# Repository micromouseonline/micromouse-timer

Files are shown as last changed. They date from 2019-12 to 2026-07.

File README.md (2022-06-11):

# micromouse-timer
Hardware and software for a micromouse classic contest timing system

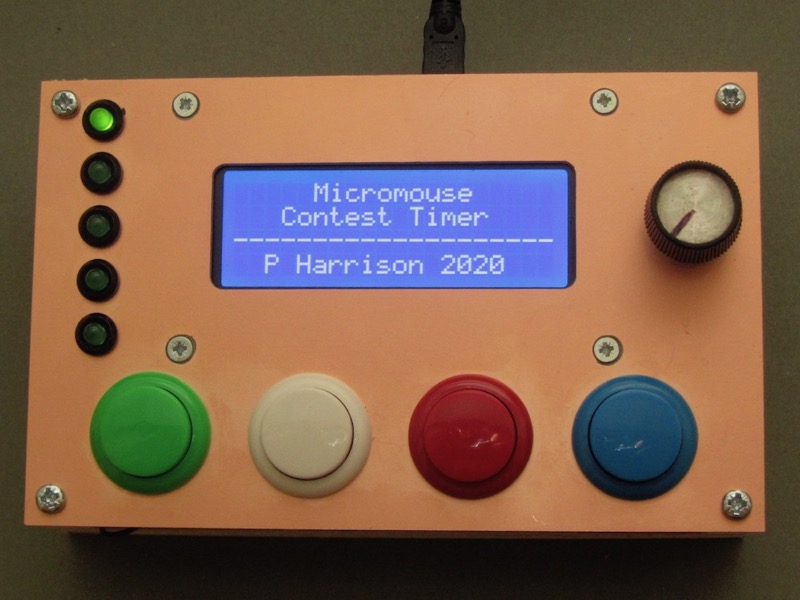
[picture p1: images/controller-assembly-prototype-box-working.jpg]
First prototype


## Design goals
Many micromouse timing systems rely on devices placed in the posts to create a break-beam arrangement. An emitter in one post produces an optical signal that is detected by a matched receiver in the other post. Commercial break-beam devices are available from companies like Omron but they are very expensive, Simpler arrangements an be made with just an LED and phototransistor. For the most reliable operation, the measuring setup really needs to control both the emitter and detector synchronously so that it can detect the breaking of the beam under a wide range of ambient lighting conditions.

This need to connect one controller to both posts makes it necesary to get access to the posts from under the maze. Not only will that require the maze to be raised off the floor by some amount, it makes it very difficult to move the gates after the maze has been set up. Ideally, any timing system should not need any physical connections between components in the maze.

The APEC maze uses a gate sensor system that can be placed anywhere and only needs to be present on one side of the opening. It manages this by using a reflective sensor that measures the distance to the far post. These sensors are similar to those used in the popular Sharp distance sensors by they are have a much faster response time. The Sharp sensors canot be polled every milisecond to get high resolution timing. Unfortunately, making the reflective sensors is quite complicated and requires a certain amount of signal processing circuitry. It is not something that is terribly easy to reproduce.

When making a timing gate sensor, consideration must be given to the robots in the maze. They typically generate very high intensity pulses of IR or visible red light from multiple emitters at 1000Hz or more. Not only should the timing system be unaffected by these pulses, it should also not interfere with the robot's ablity to make measurements. Thus, the robot must not cause timing errors and the timing syste must not make the robots crash.

Finally, there is the issue of ambient lighting levels. These are variable from venue to venue and may vary greatly even during a contest. A venue with natural light may have direct sunlight into the room and, clearly, that light will move around during the day. Other sources of interfering ambient light might include camera lights and camera flashguns. theese too should not interfere with the operation of the timing system.

With so many constraints, it would be natural to seek ever more sophisticated solutions to overcome them.

After several experiments with 'clever' designs, this project tries to make everything as simple as possible.

## Components
There are four components for this timing system
1. gate emitters  - these are just blue LEDs connected to a single Lithium cell with a single current limit resistor. They operate continuously for up to 36 hours between charges.
2. gate receivers - these have a phototransistor with a single load resistor connected to an analogue input channel on an Arduino. The Arduino is also connected to a small 433MHz radio module so that it can send detected changes to a timing controller. Again, a single Lithium cell provides power for at least 20 hours operation.
3. gate controller - the controller is connected directly to the timing management computer with a USB-serial link. It also has a radio receiver so that it can obtain event information from the gate receivers. Each gate receiver sends encoded packets to identify the event and the gate ID. The controller performs the actual timing function and all the data can be stored on an SD card for independent operation or to provide a backup. Power can come from the host USB connection, batteries or a separate power supply. Optionally, a Bluetooth conenction could be made to the host. Sinca all the communication with the gates is wireless, the controller can be placed several metres away from the maze and there are no trailing wires to the maze.
4. timing manager - the software running on the host computer that accepts timing information from the controller, presents it on the display screens and maintains the contest results.

## Gate Operation
Each gate has an emitter and a receiver.

### Emitters
The emitter generates a continuous beam of illumination using blue light. Green light would be a good alternative. While apparently very bright to the human eye, typical micromouse sensor will be relatively insensitive to these wavelengths and, in any case, will perceive the illumnation as part of the background and so it should be compensated for. Blue LEDs have quite high forward voltages of around 2.8 to 3.0 Volts but can still be run from a single Lithium cells with a small series current limiting resistor. Using a resistor value of 39 Ohms with the chosen device limits the maximum current to around 27mA with a fully charged battery at 4.2Volts. As the battery discharges to a nominal 3.7 Volts, the current decreases to about 15mA.

The battery is a Nokia BL-4S with a nominal capacity of 860 mAhr. Once turned on, there should be sufficient capacity for at least 36 hours operation.

A TP4056-based battery charge and protect circuit prevents over discharge of the battery and allows for easy re-charging from a 5V source such as a cell-phone charger of portable power bank.

The emmitter assembly is entirely contained within a typical plastic classic wall. Light shines through a hole in the end of the wall and a corresponding hole is a post. Where the gate must be perpendicular to the wall, a special post is used that contains an embedded reflector at 45 degrees. The reflecto involves a failry large aamount of light loss but is still sufficent for the task. Straight-through emitters might benefit from lower intensity and this could be provided with an additional switch to change the current limit resistor.

### Detectors
The detector circuit is minimal. It consistes of a TEPT5600 visible light phototransistor with a 2200Ohm load resistor on the emitter. The transistor emitter is connected directly to an analogue channel on an arduino mini-pro. The load resistor is selected to give a reading of between 20 and 60 counts when illuminated only by the LED in the timing gate in its normal operating configuration. This is quite a low sensitivity but it ensures that operation will be relatively unaffected even by quite bright ambient illumination right up to the point of saturation of the phototransistor

Attached to a software serial TX pin on the Arduino is a self-contained radio transeiver used only in its transmit mode. the radio is powered down until the gate is interrupted. When messages are to be sent, the radio is powered up, placed in transmit mode and the message is transmitted several times to ensure reliable communication. Aferards, the radio is powered down again to reduce current consumption and prevent interference.

All the radios in the system operate on the same frequency but there should be no natural circumstance where more than one transmits at a time. Thus, the controller needs only one radio and can distinguish the message source from its content.

Like the emitter, the circuitry all fits inside a typical classic maze wall and runs from a BL-4S battery using the same type of TP4056 charge/protect module. In normal operation, the Arduino draws only 12mA and the brief periods of transmission double that for a second or two. Continuous operation should be possible for at least 50 hours with a fully charged BL-4S battery.

### Controller
At the heart of the timing operation is the controller. An Arduino is connected to another LINX radio module which is running continuously in receive mode. It listens for packets from the gate detectors and runs a state machine that looks after all the timing functions related to the current contest.

While intended primarily for micromouse, the same controller could be used for drag race, line follower and time trial contests. Some additional care would be needed to distinguish the transmissions from gates in other contests. The controller passes timing and event notfications to the host computer running event management software using a USB-serial bridge. The same connection can provide power.

So that the controller can be used stand-alone and/or act as a backup to automatic timing, it also has an LCD display and a number of manual buttons that set the state of the system and provide manual gate inputs if needed.

Internally, an SD card records all the incoming and outgoing messages so that they can be retreived for later analysis and toserve as an auxiliary store in case of an error or failure in the management software. Files are time stamped using a data from a battery-backed real time clock module. Note that the RTC battery is not rechargeable and annual maintenance should be carried out to replace the battery and ensure thatthe time and date are correct.

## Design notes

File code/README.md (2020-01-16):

# Micromouse Timer Code

Each folder is a PlatformIO project under Visual Studio Code. The projects should also build under the Arduin IDE if you open the appropriate ___.ino file.

For the operation of the timer hardware, there are just two projects. The gate-detector runs the hardware inside each gate. All the gates run the same code. The gate-controller is the master control box that receives messages from the gates and actually does the timing.

The controller can be run stand-alone. Separate software would be needed for recording the times on a host computer and for the generation of a contest display.

Other projects here are used to test the various parts of the hardware.

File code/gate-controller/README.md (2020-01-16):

# Timing gate Controller

All of the actual timing decisions are made by the gate controller. This device is an Arduino nano with a number of attached peripheral devices incuding a radio receiver that listens for event essages from the individual gates. The controller can be configured for a number of different rule sets and contest types. For the 'standard' micromouse event, the controller keeps track of total maze time, current run time and best run time for that entry. There is no information stored in the controller about which mouse is running.

## Front Panel

On the front panel are a 20x4 LCD character display and an encoder/switch for altering the current mode and operating any other UI on the controller. Four buttons allow the controller to be operated manually if the gates are not functioning or not present. As well as a power indicator, four LEDs indicate the current state of the controller and the events driving it.

## Connectivity

Although it can operate in a completely stand-alone mode, the controller would normally be connected to a host computer that will keep a record of the run times and look after any dislay devices for the conestants and spectators. Communication with the host is performed over a serial link (at 57600 baud) using the Arduino's built-in serial bridge. This has two side-effects. One is that the device can be programmed over the same link, the other is that connecting the cable will reset the controller. Since this connection is also how it gets its power, that is not a great problem.

Optionally, the internal BlueTooth transeiver can be used for serial communications if a plain USB power supply is used. The communications speed is still 57600 baud and the two serial connections share the same USART of the Arduino.

## Storage

Also present are a micro SD card reader/writer and a Real Time CLock. The SD card interface makes it possible for al messages and times to be saved to a suitable SD Card for subsequent analysis and reporting or in case the host connection fails or is not present. With the time data from the RTC, files and events can be properly time stamped. Note that the RTC is battery backed but does not incorporate a charger. The battery life of the clock is given as 1 year. Without the battery, all times will be relative to the last application of pwer to the device.

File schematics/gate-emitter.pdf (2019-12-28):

28/12/2019 09:20 /Users/peterharrison/OneDrive/Documents/eagle/projects/Timing-Gate/gate-emitter.sch (Sheet: 1/1)

BATTERY-CHARGER-LI-PROT

3.3V

GND

OVLGB0C6B9 | OVLGB0C6B9
GND | GND
39R | 39R | B+B-

IN+

IN-

OUT+ OUT- | +

+
ID

ID

D1 | D2
R1 | R2

## Sheet:

A

B

C

D

1 | 2 | 3 | 4 | 5 | 6

A

B

C

D

1 | 2 | 3 | 4 | 5 | 6

## gate-emitter

28/12/2019 09:19
1/1
USB | NOKIA BL-4S

The start gate uses two sensors. one across the posts and one about 2/3 of the way back into the cell. Goal gates use only one sensor placed across the posts. The post sensor is D1/R1

If the other sensor is not used, omit both R2 and D2

OVLGB0C6B9 is a high intensity, narrow beam blue 5mm LED.

The battery can be any LiPo or LiIon
single cell type that will fit. The Nokia BL-4S has a capacity of 860mA

and is a perfect size to fit inside a classic wall. Circut power consumption is a few tens of mA

at idle.

Battery management is provided by an ebay module holding a TP4056 charger along with a discharge protection circuit. Micromouse Timer Gate Emitter

# (c) 2019 Peter Harrison https://github.com/micromouseonline/micromouse-timer

S1 is a small slide switch sized to fit inside the wall. surfacemount types are suitable here. Use anything

that will fit.

Peter Harrison

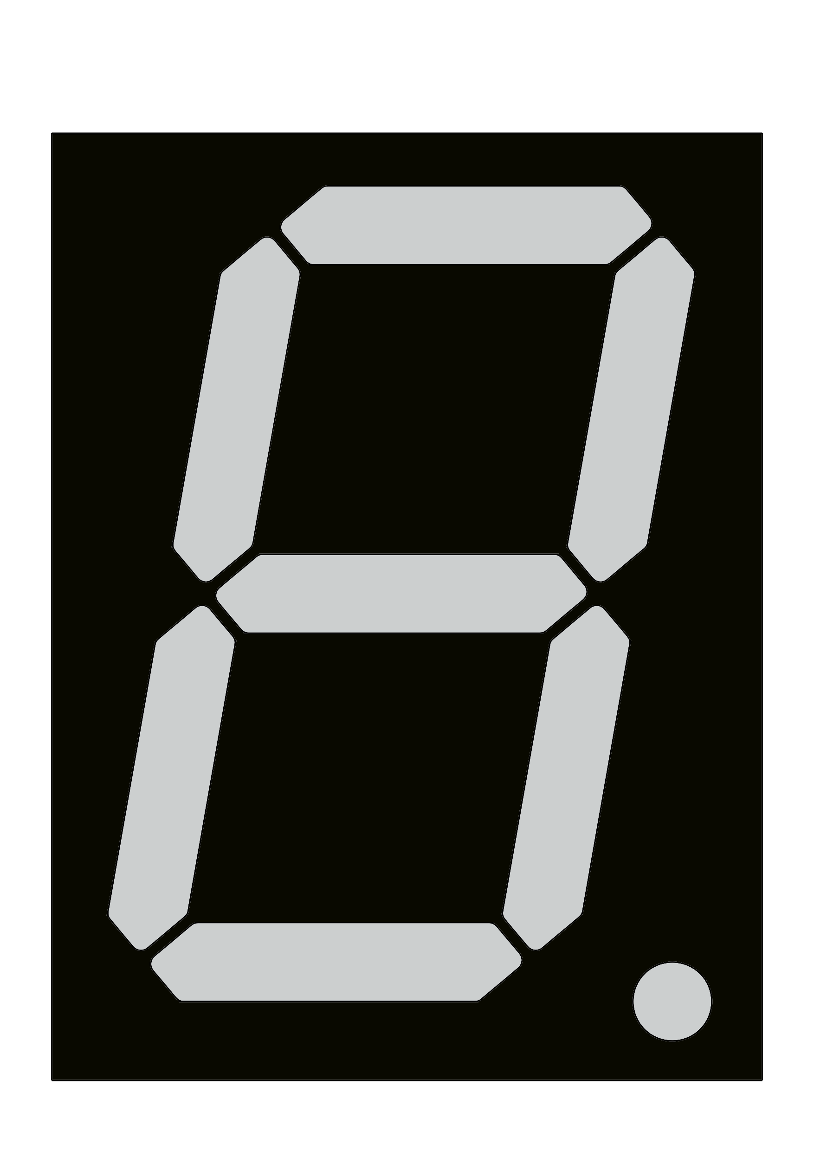
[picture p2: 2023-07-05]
hardware/seven-segment-display/single-digit-mask.png

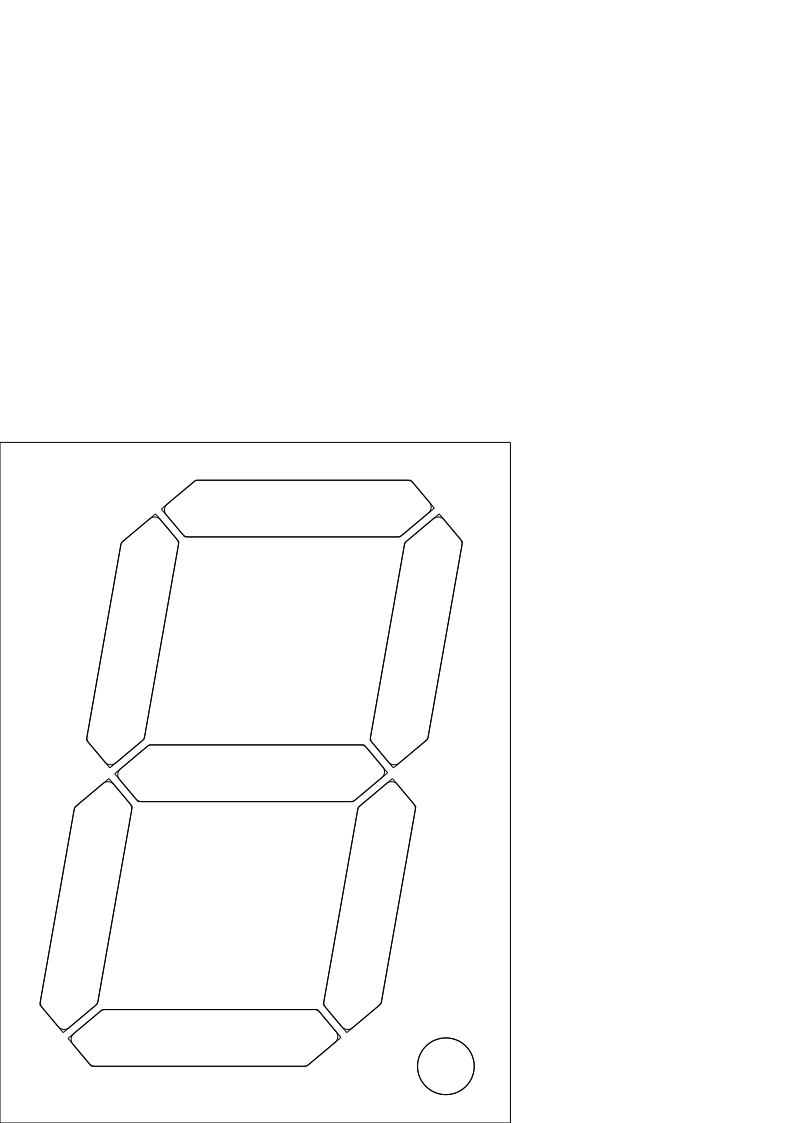
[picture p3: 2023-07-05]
hardware/seven-segment-display/single-digit.png

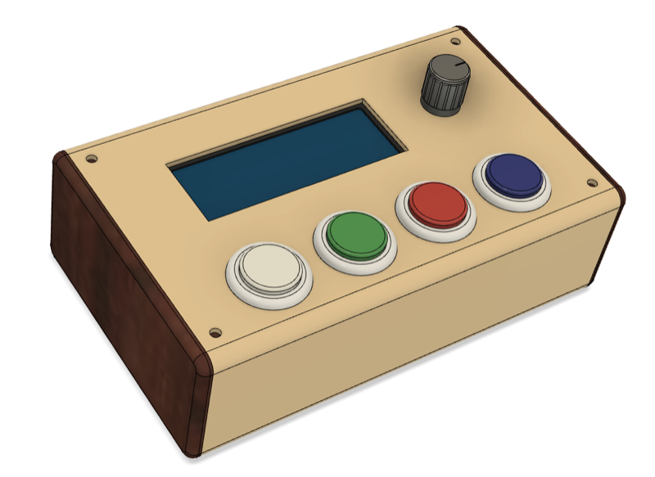
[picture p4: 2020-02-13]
images/controller-render-V2a.png

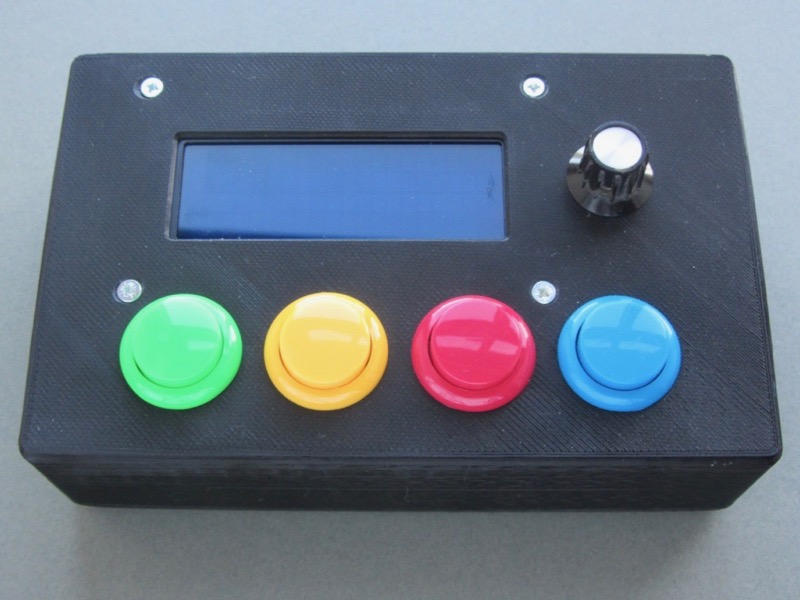
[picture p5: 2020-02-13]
images/controller-boxed.jpg

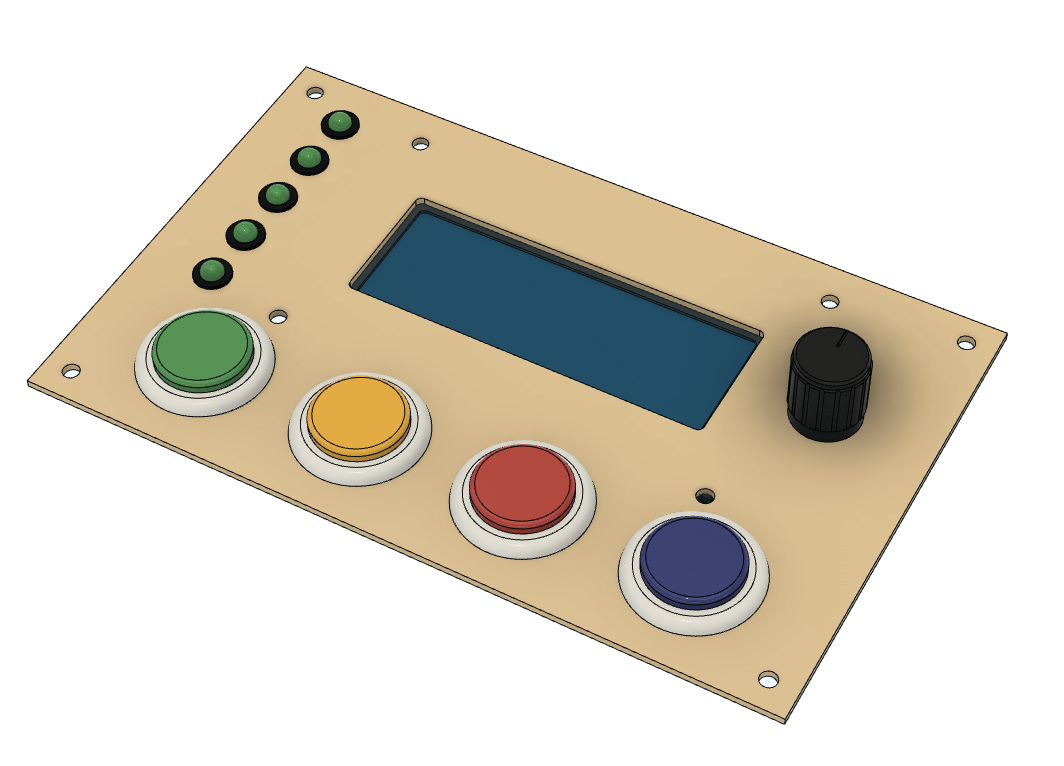
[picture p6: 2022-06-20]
images/front-panel.png

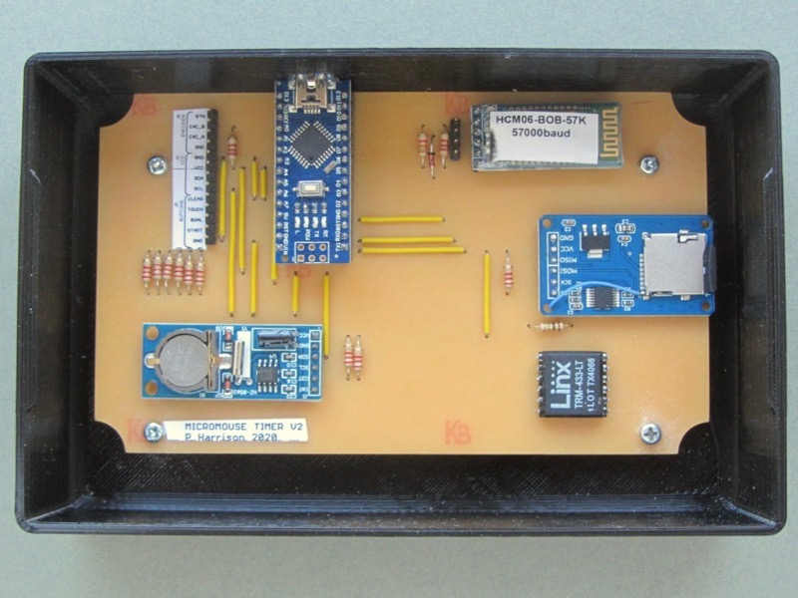
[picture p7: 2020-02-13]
images/controller-circuit-board.jpg

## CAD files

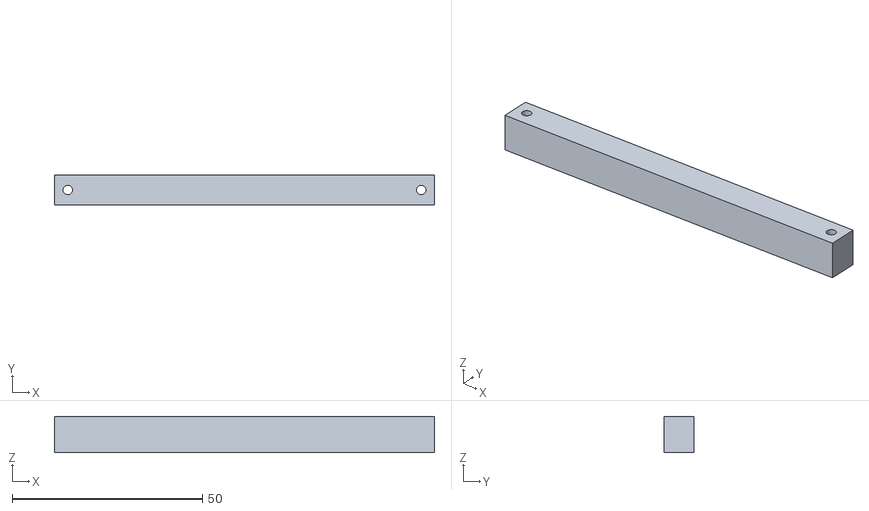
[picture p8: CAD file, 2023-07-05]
hardware/controller-enclosure/LCD-spacer.stl
100.0 x 8.00 x 9.60

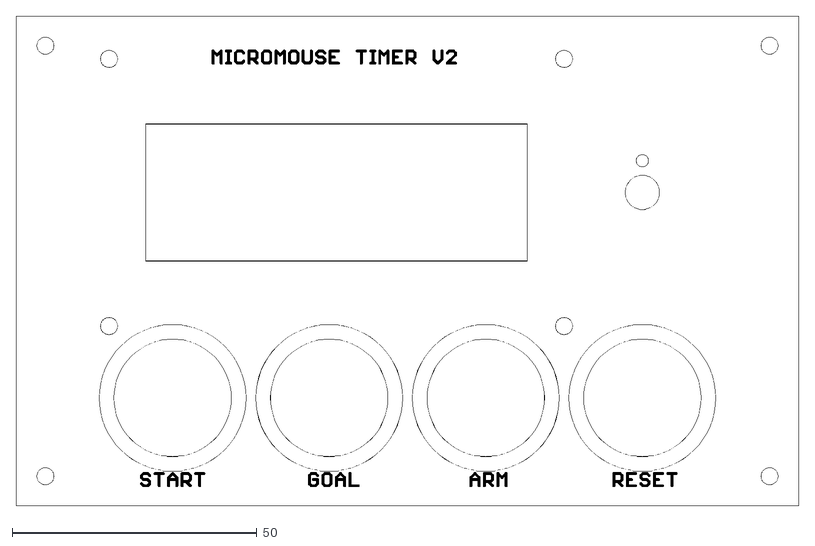
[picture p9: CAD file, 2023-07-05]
hardware/controller-pcb/gate-controller-top-pane-plywoodl.dxf
160.0 x 100.0

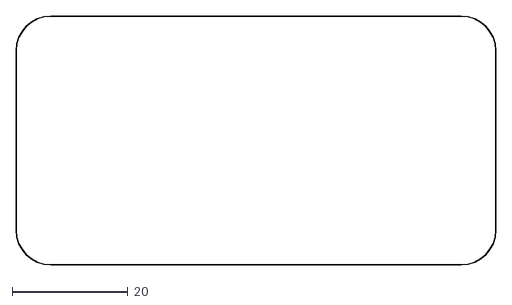
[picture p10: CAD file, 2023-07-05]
hardware/gate-charger/4-way-charger-outline.dxf
83.0 x 43.0

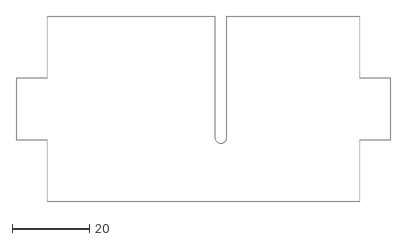
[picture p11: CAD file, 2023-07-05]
hardware/gate-detector/gate-detector.dxf
97.1 x 48.1

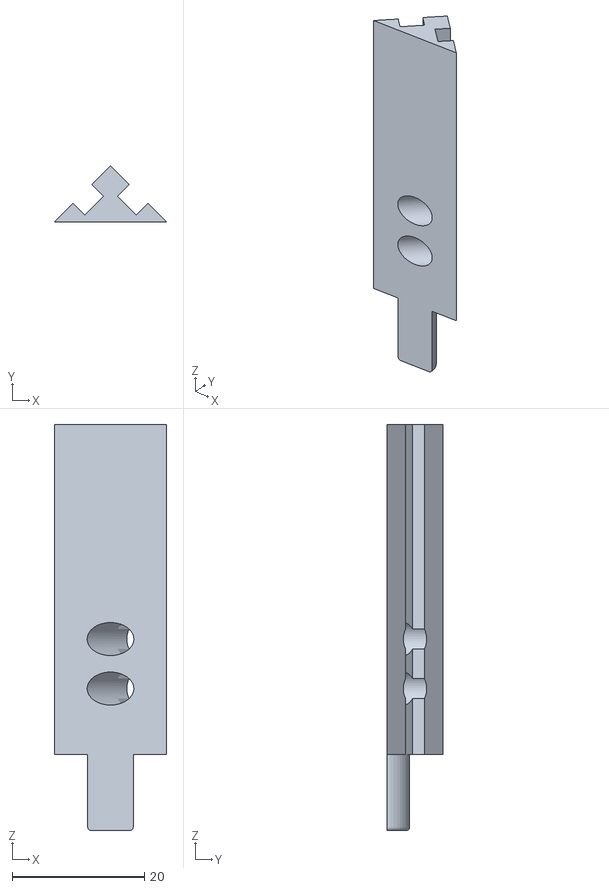
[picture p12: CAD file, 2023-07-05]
hardware/gate-post-and-wall-parts/post-half-double-sensor-one-way.stl
17.0 x 8.49 x 61.5

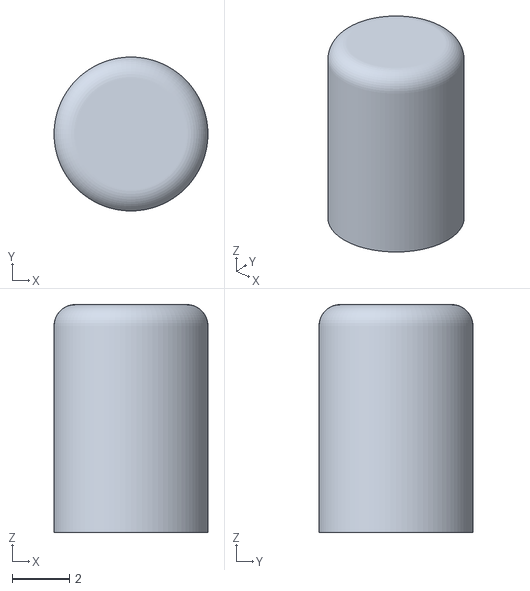
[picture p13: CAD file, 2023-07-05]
hardware/seven-segment-display/dp-small.stl
5.40 x 5.40 x 8.00

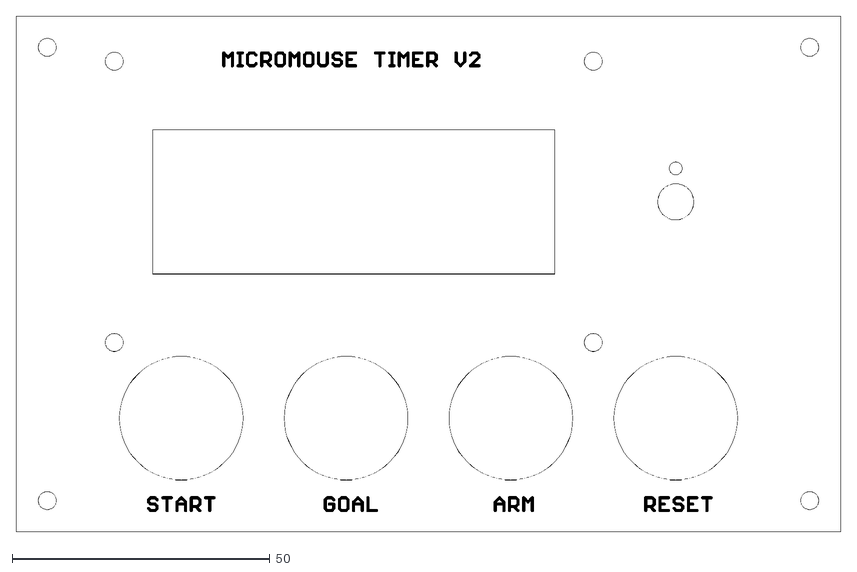
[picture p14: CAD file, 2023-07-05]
hardware/controller-enclosure/gate-controller-top-panel.dxf
160.0 x 100.0

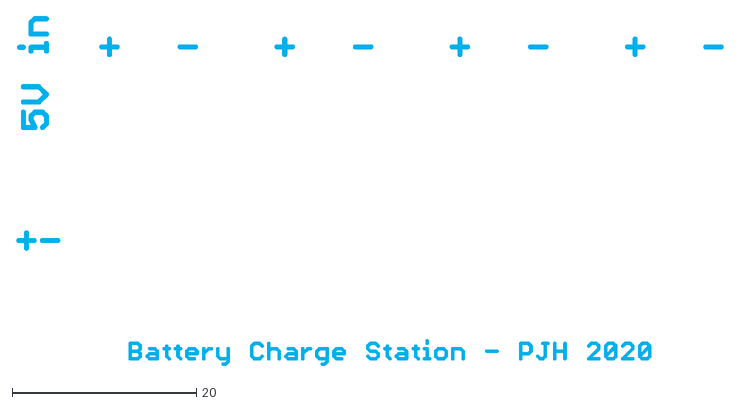
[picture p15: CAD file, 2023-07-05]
hardware/gate-charger/4-way-charger-text.dxf
76.7 x 37.9

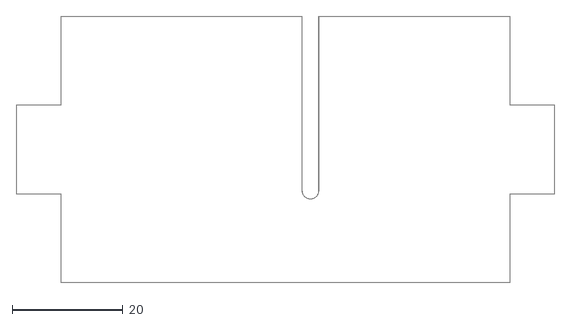
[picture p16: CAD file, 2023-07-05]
hardware/gate-detector/gate-detector-board-outline.dxf
97.1 x 48.1

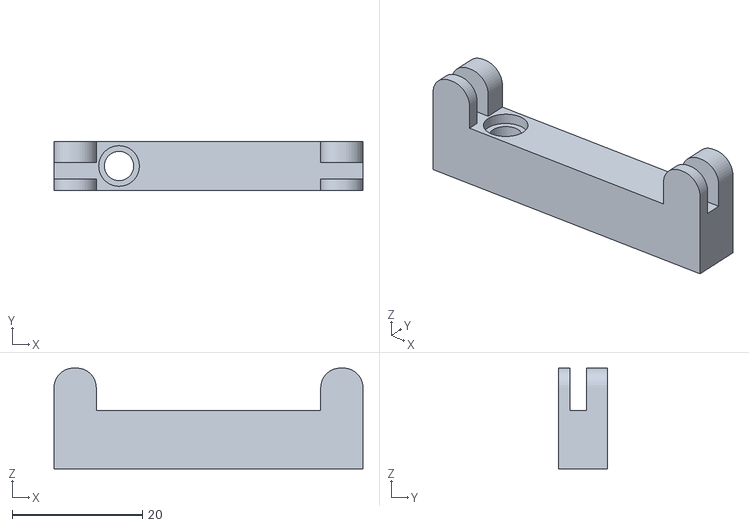
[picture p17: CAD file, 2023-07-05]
hardware/gate-post-and-wall-parts/emitter-holder.stl
47.5 x 7.50 x 15.5

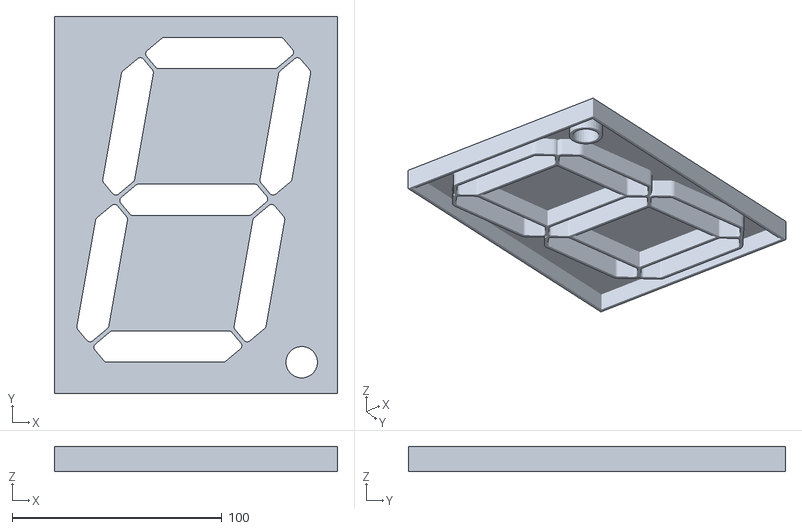
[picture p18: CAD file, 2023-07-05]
hardware/seven-segment-display/seven-sement-shield.stl
135.0 x 180.0 x 12.0

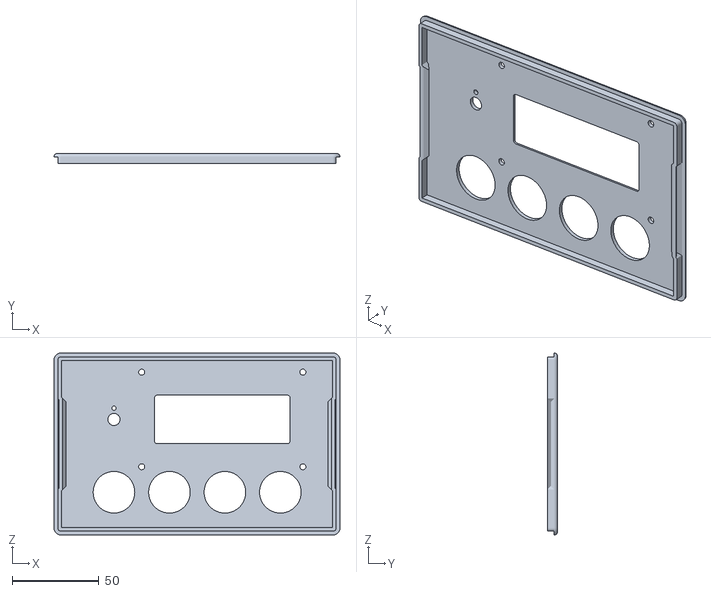
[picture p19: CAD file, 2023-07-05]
hardware/controller-enclosure/gate-controller-case-lid.stl
165.0 x 6.00 x 105.0

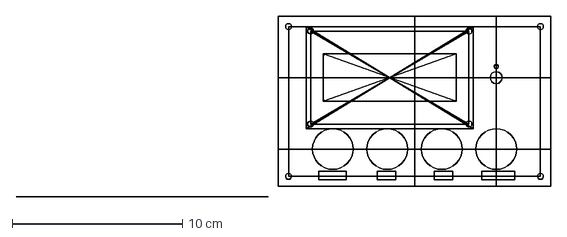
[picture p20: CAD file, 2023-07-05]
hardware/controller-pcb/gate-controller-Front Panel V2 v6.dxf
31.4 x 10.6 cm

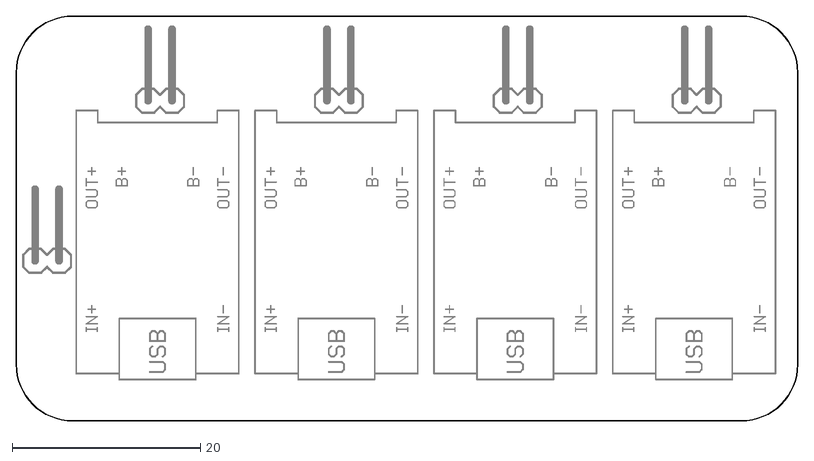
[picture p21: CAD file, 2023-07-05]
hardware/gate-charger/4-way-charger-fill.dxf
83.0 x 43.0

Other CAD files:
hardware/gate-detector/gate-detector-mirrored (copy).dxf
hardware/gate-post-and-wall-parts/classic-post-half-sensor-hole.stl
hardware/seven-segment-display/seven-segment-body-upright-milled.dxf
hardware/controller-enclosure/controller-panel.stl
hardware/controller-enclosure/gate-controller-V2.dxf
hardware/controller-enclosure/gate-controller-case-body.stl
hardware/controller-enclosure/spacer-9.6mm.stl
hardware/controller-pcb/gate-controller-case-body.stl
hardware/controller-pcb/gate-controller-mirrored-V2.dxf
hardware/gate-charger/4-way-charger-brd-nofill.dxf
hardware/gate-detector/gate-detector-mirrored.dxf
hardware/gate-post-and-wall-parts/detector-holder-v2.stl
hardware/gate-post-and-wall-parts/detector-holder.stl
hardware/gate-post-and-wall-parts/emitter-detector-twin-holder.stl
hardware/gate-post-and-wall-parts/maze-gate-emitter-detector-holder-v2.stl
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

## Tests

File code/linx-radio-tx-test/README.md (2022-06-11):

# Linx radio transmission/reception tests

The Linx TRM-433 tranceiver modules are simple On-Off Keying (OOK) devices operating in the 433MHx radio band. The same device is also available in other bands appropriate to their country of use and local radio regulations.

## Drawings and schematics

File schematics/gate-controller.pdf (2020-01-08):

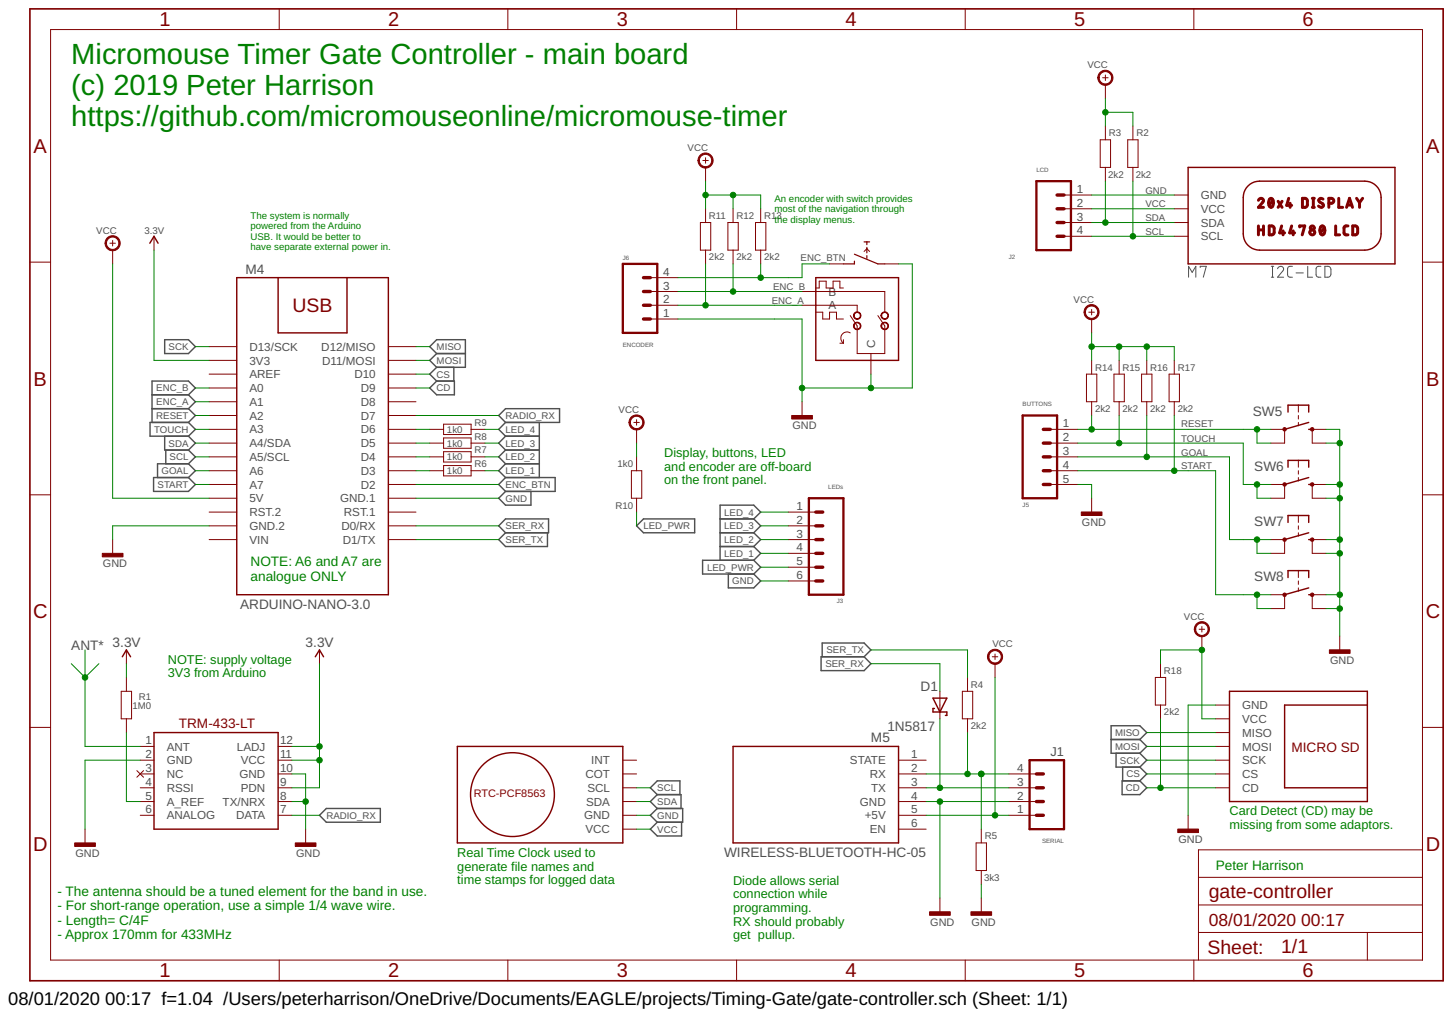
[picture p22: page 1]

Micromouse Timer Gate Controller - main board VCC

(c) 2019 Peter Harrison
https://github.com/micromouseonline/micromouse-timer

3V3 D13/SCK M4
USB
D1/TX D0/RX RST.1 GND.1 D2 D3 D4 D5 D6 D7 D8 D9 D10 D11/MOSI D12/MISO
A3A2A1A0AREF

An encoder with switch provides most of the navigation through
the display menus.

2 | | VCC
3 | | SDA
4 | | SCL

The system is normally powered from the Arduino USB. It would be better to

have separate external power in.

Display, buttons, LED
and encoder are off-board

on the front panel. NOTE: A6 and A7 are
VIN GND.2 RST.2

VCC MISO MOSI SCK CS

INT COT SCL SDA GND

4 +5V | 2
5 EN | 1

Card Detect (CD) may be missing from some adaptors. Diode allows serial connection while

Real Time Clock used to
generate file names and
time stamps for logged data

- The antenna should be a tuned element for the band in use. - For short-range operation, use a simple 1/4 wave wire. - Length= C/4F

programming. RX should probably
get pullup.

08/01/2020 00:17 f=1.04 /Users/peterharrison/OneDrive/Documents/EAGLE/projects/Timing-Gate/gate-controller.sch (Sheet: 1/1)

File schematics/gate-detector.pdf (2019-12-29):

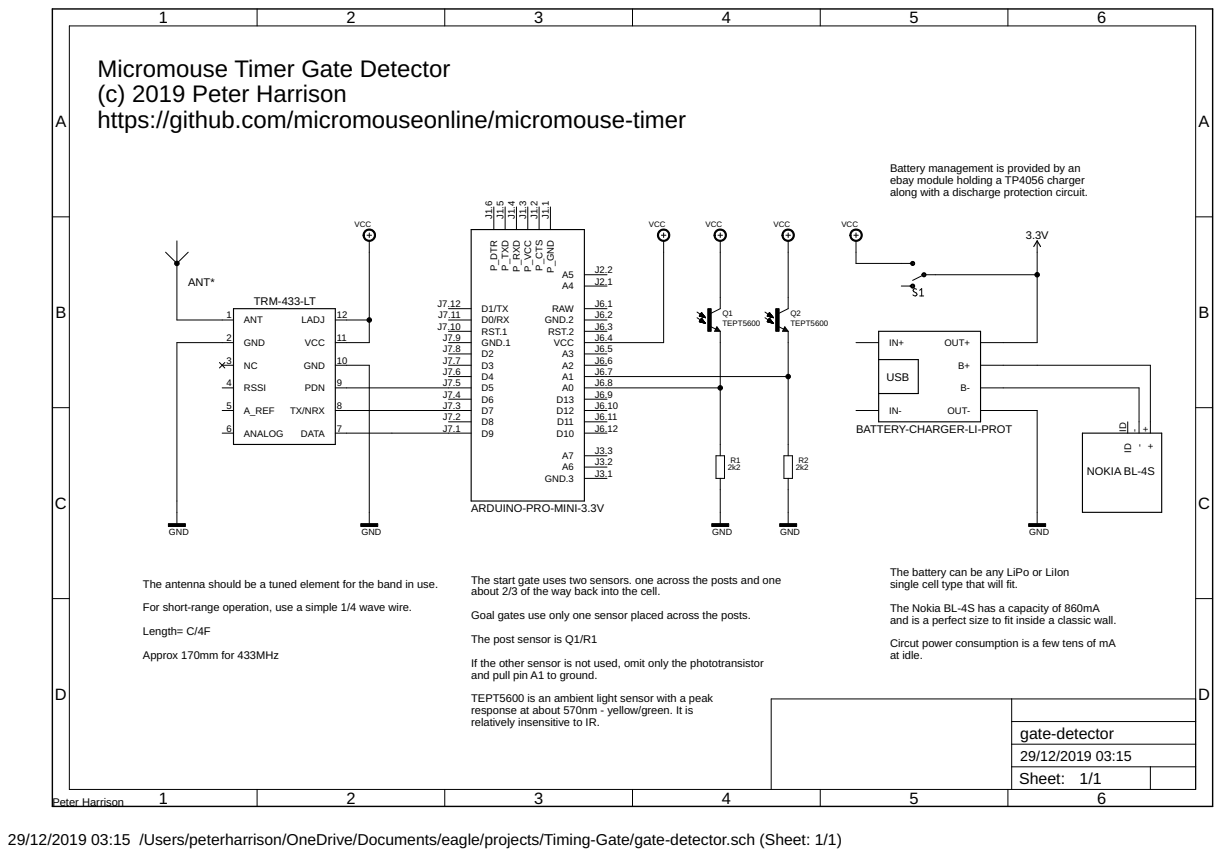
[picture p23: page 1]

ebay module holding a TP4056 charger along with a discharge protection circuit. Micromouse Timer Gate Detector
(c) 2019 Peter Harrison
https://github.com/micromouseonline/micromouse-timer

Battery management is provided by an

BATTERY-CHARGER-LI-PROT
2k2 GND

The start gate uses two sensors. one across the posts and one
about 2/3 of the way back into the cell. Goal gates use only one sensor placed across the posts. The post sensor is Q1/R1

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

If the other sensor is not used, omit only the phototransistor and pull pin A1 to ground. TEPT5600 is an ambient light sensor with a peak

response at about 570nm - yellow/green. It is
relatively insensitive to IR.

29/12/2019 03:15 /Users/peterharrison/OneDrive/Documents/eagle/projects/Timing-Gate/gate-detector.sch (Sheet: 1/1)

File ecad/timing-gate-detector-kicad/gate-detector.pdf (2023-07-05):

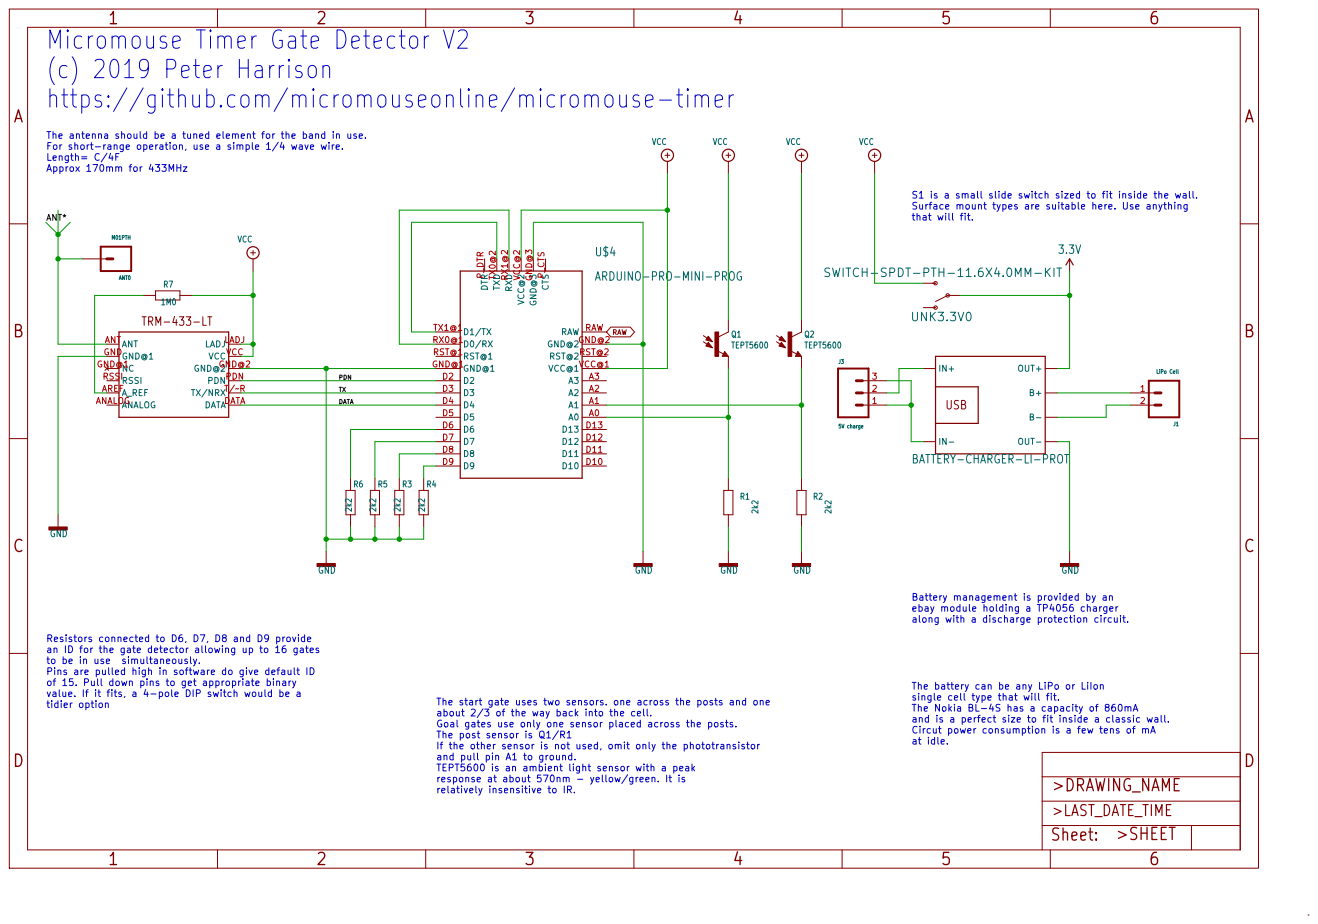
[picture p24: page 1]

at idle. Micromouse Timer Gate Detector V2
(c) 2019 Peter Harrison
https://github.com/micromouseonline/micromouse-timer

that will fit. The antenna should be a tuned element for the band in use. For short-range operation, use a simple 1/4 wave wire.

S1 is a small slide switch sized to fit inside the wall. Surface mount types are suitable here. Use anything

ARDUINO-PRO-MINI-PROG R7

ebay module holding a TP4056 charger
along with a discharge protection circuit.

Resistors connected to D6, D7, D8 and D9 provide
an ID for the gate detector allowing up to 16 gates
to be in use simultaneously.
Pins are pulled high in software do give default ID
of 15. Pull down pins to get appropriate binary
value. If it fits, a 4-pole DIP switch would be a
tidier option

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

The start gate uses two sensors. one across the posts and one
about 2/3 of the way back into the cell.
Goal gates use only one sensor placed across the posts.
The post sensor is Q1/R1
If the other sensor is not used, omit only the phototransistor
and pull pin A1 to ground.
TEPT5600 is an ambient light sensor with a peak
response at about 570nm - yellow/green. It is
relatively insensitive to IR.

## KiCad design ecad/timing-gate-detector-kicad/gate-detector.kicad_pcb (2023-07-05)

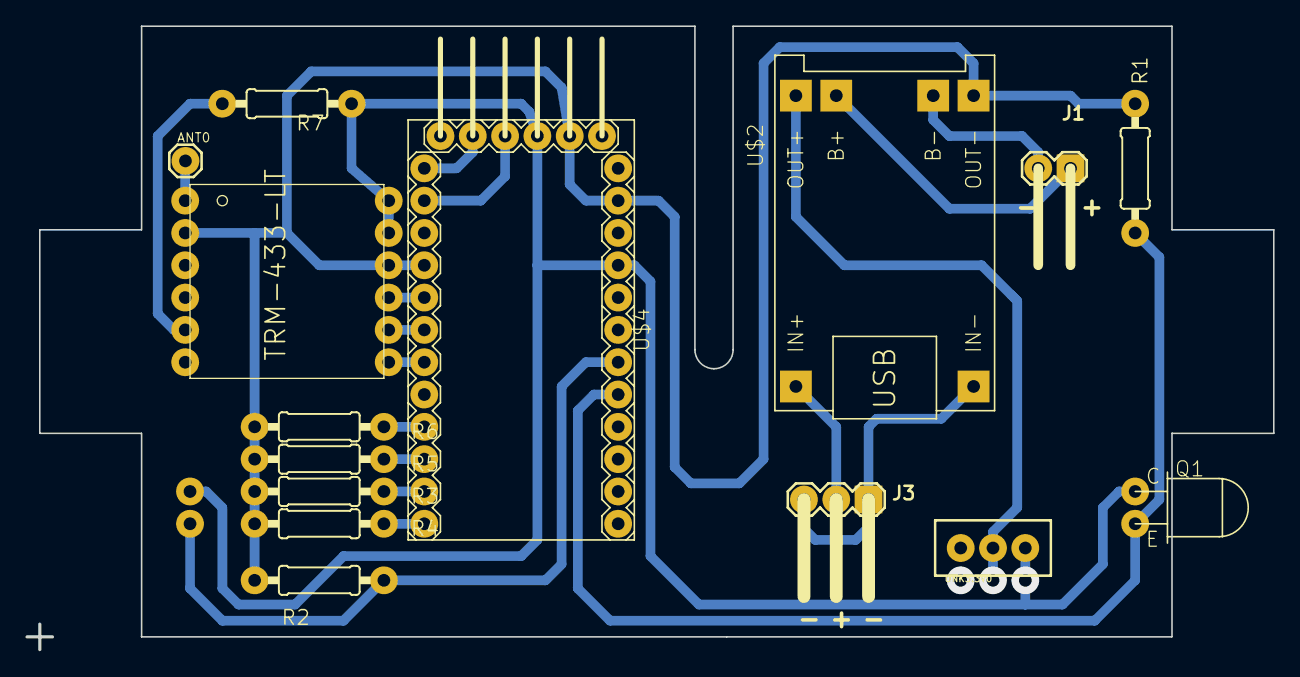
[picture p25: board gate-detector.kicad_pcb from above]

Board: 6 copper layers, 98.0 x 49.0 mm, 16 parts (1 on the bottom side), 20 nets.

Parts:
ANT0: M01PTH; 1X01
J1: LiPo Cell; 1X02_RA_PTH_MALE_MILL
J3: 5V charge; 1X03_RA_PTH_MILL
Q1, Q2: TEPT5600; PHOTOTRANSISTOR-TO5-SIDE
R1, R2, R3, R4, R5, R6: 2k2; AXIAL-0207_0.4
R7: 1M0; AXIAL-0207_0.4
U$1: TRM-433-LT; LINX-TRM-433-LT
U$2: BATTERY-CHARGER-LI-PROT
U$4: ARDUINO-PRO-MINI-PROG
UNK3.3V0: SWITCH_SPDT_PTH_11.6X4.0MM_KIT

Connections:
3.3V: U$2.OUT+, UNK3.3V0.2
ANT*: ANT0.1, U$1.ANT
DATA: U$1.DATA, U$4.D4
GND: R1.1, R2.1, R3.1, R4.1, R5.1, R6.1, U$1.GND, U$1.GND@2, U$2.OUT-, U$4.GND@1, U$4.GND@2, U$4.GND@3
unnamed: Q2.E, R2.2, U$4.A1
unnamed: J1.1, U$2.B+
unnamed: R4.2, U$4.D9
unnamed: R3.2, U$4.D8
unnamed: R5.2, U$4.D7
unnamed: Q1.E, R1.2, U$4.A0
unnamed: J1.2, U$2.B-
unnamed: R6.2, U$4.D6
unnamed: R7.2, U$1.AREF
unnamed: J3.2, U$2.IN+
unnamed: J3.1, J3.3, U$2.IN-
unnamed: U$4.TX0@2, U$4.TX1@1
unnamed: U$4.RX0@1, U$4.RX1@2
PDN: U$1.PDN, U$4.D2
TX: U$1.T/~R, U$4.D3
VCC: Q1.C, Q2.C, R7.1, U$1.LADJ, U$1.VCC, U$4.VCC@1, U$4.VCC@2, UNK3.3V0.3

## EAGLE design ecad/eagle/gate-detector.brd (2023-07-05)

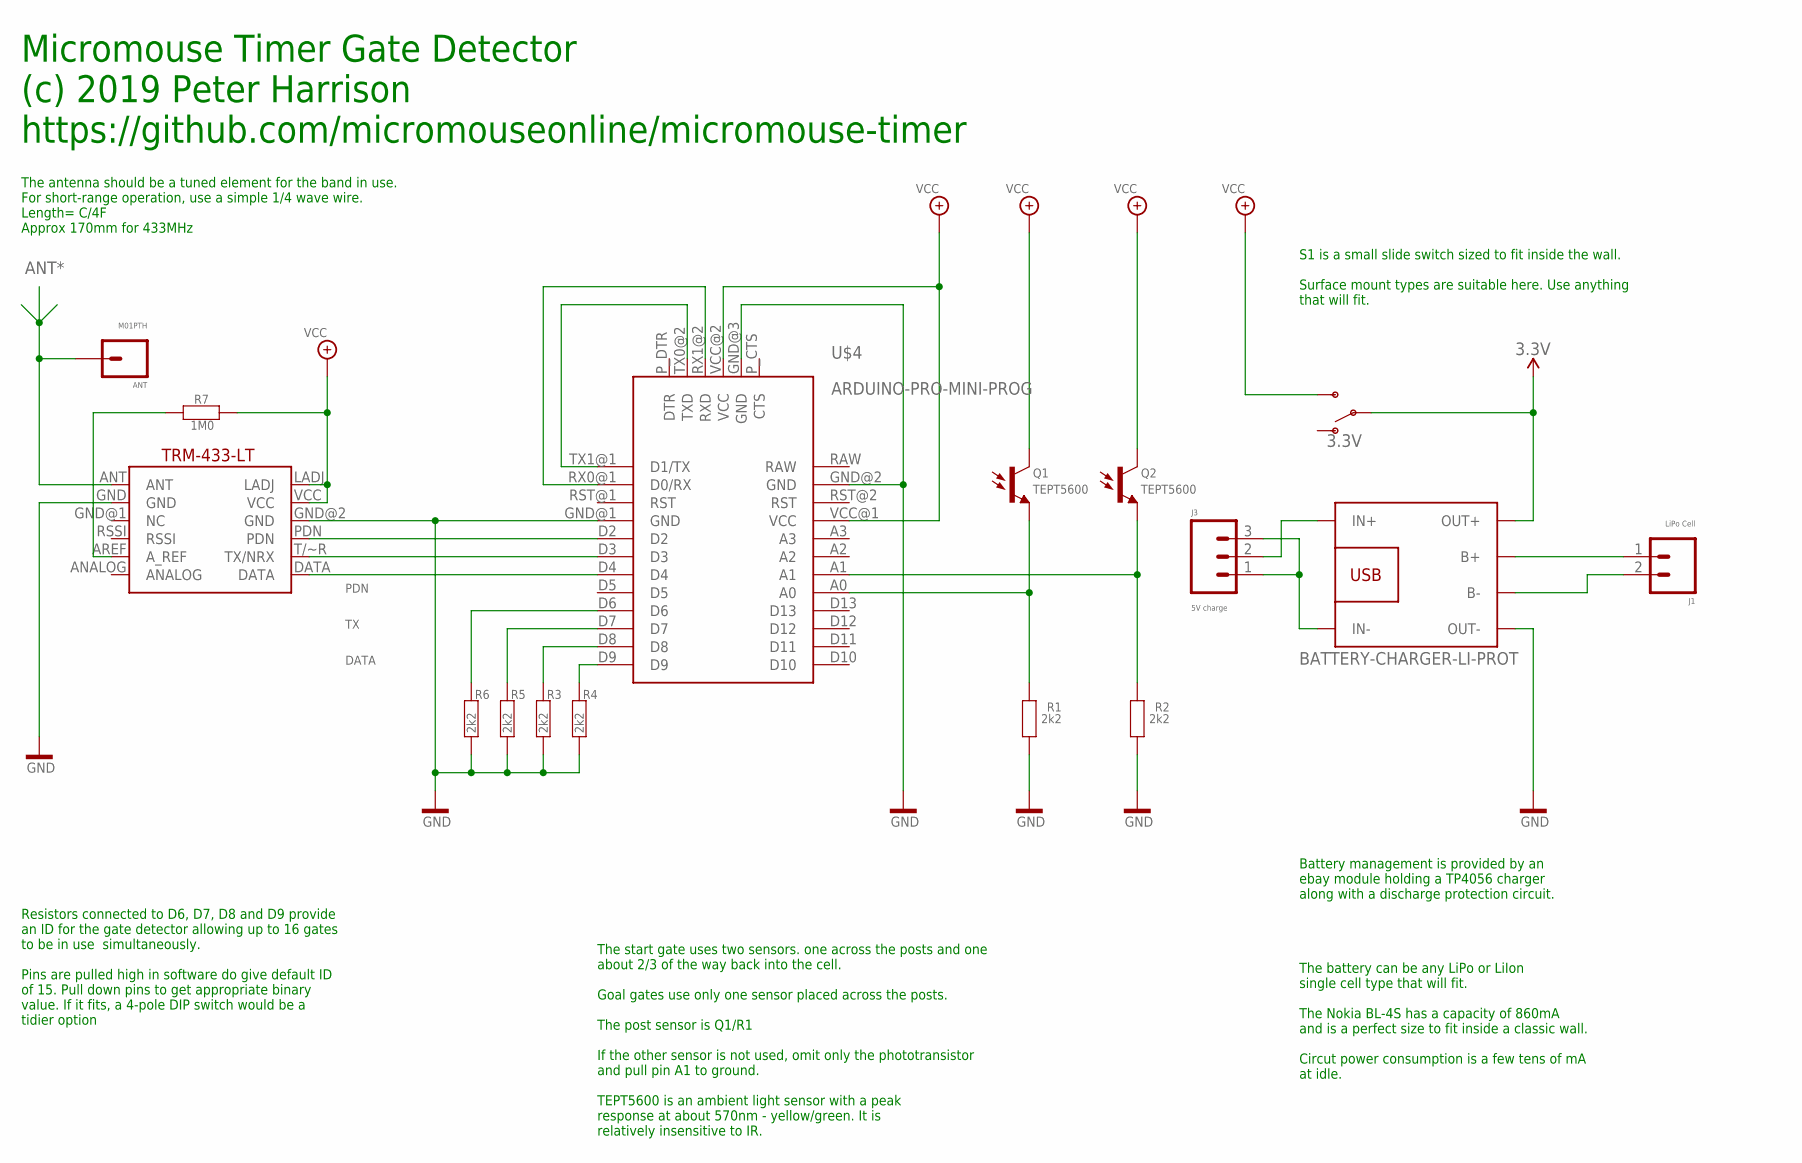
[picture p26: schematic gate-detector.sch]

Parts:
3.3V: SWITCH-SPDT-PTH-11.6X4.0MM-KIT; SWITCH_SPDT_PTH_11.6X4.0MM_KIT
ANT: M01PTH; 1X01
J1: LiPo Cell; 1X02_RA_PTH_MALE_MILL
J3: 5V charge; 1X03_RA_PTH_MILL
Q1, Q2: TEPT5600; PHOTOTRANSISTOR-TO5-SIDE
R1, R2, R3, R4, R5, R6: 2k2; AXIAL-0207_0.4
R7: 1M0; AXIAL-0207_0.4
U$1: TRM-433-LT; LINX-TRM-433-LT
U$2: BATTERY-CHARGER-LI-PROT
U$4: ARDUINO-PRO-MINI-PROG

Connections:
3.3V: 3.3V.2, U$2.OUT+
ANT*: ANT.1, U$1.ANT
DATA: U$1.DATA, U$4.D4
GND: R1.1, R2.1, R3.1, R4.1, R5.1, R6.1, U$1.GND, U$1.GND@2 (GND), U$2.OUT-, U$4.GND@1 (GND), U$4.GND@2 (GND), U$4.GND@3 (GND)
unnamed: Q2.E, R2.2, U$4.A1
unnamed: J1.1, U$2.B+
unnamed: R4.2, U$4.D9
unnamed: R3.2, U$4.D8
unnamed: R5.2, U$4.D7
unnamed: Q1.E, R1.2, U$4.A0
unnamed: J1.2, U$2.B-
unnamed: R6.2, U$4.D6
unnamed: R7.2, U$1.AREF (A_REF)
unnamed: J3.2, U$2.IN+
unnamed: J3.1, J3.3, U$2.IN-
unnamed: U$4.TX0@2 (TXD), U$4.TX1@1 (D1/TX)
unnamed: U$4.RX0@1 (D0/RX), U$4.RX1@2 (RXD)
PDN: U$1.PDN, U$4.D2
RAW: U$4.RAW
TX: U$1.T/~R (TX/NRX), U$4.D3
VCC: 3.3V.3 (S), Q1.C, Q2.C, R7.1, U$1.LADJ, U$1.VCC, U$4.VCC@1 (VCC), U$4.VCC@2 (VCC)

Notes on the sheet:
The antenna should be a tuned element for the band in use. For short-range operation, use a simple 1/4 wave wire. Length= C/4F Approx 170mm for 433MHz
The start gate uses two sensors. one across the posts and one about 2/3 of the way back into the cell. Goal gates use only one sensor placed across the posts. The post sensor is Q1/R1 If the other sensor is not used, omit only the phototransistor and pull pin A1 to ground. TEPT5600 is an ambient li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
The battery can be any LiPo or LiIon single cell type that will fit. The Nokia BL-4S has a capacity of 860mA and is a perfect size to fit inside a classic wall. Circut power consumption is a few tens of mA at idle.
Battery management is provided by an ebay module holding a TP4056 charger along with a discharge protection circuit.
Micromouse Timer Gate Detector (c) 2019 Peter Harrison https://github.com/micromouseonline/micromouse-timer
S1 is a small slide switch sized to fit inside the wall. Surface mount types are suitable here. Use anything that will fit.
Resistors connected to D6, D7, D8 and D9 provide an ID for the gate detector allowing up to 16 gates to be in use simultaneously. Pins are pulled high in software do give default ID of 15. Pull down pins to get appropriate binary value. If it fits, a 4-pole DIP switch would be a tidier option

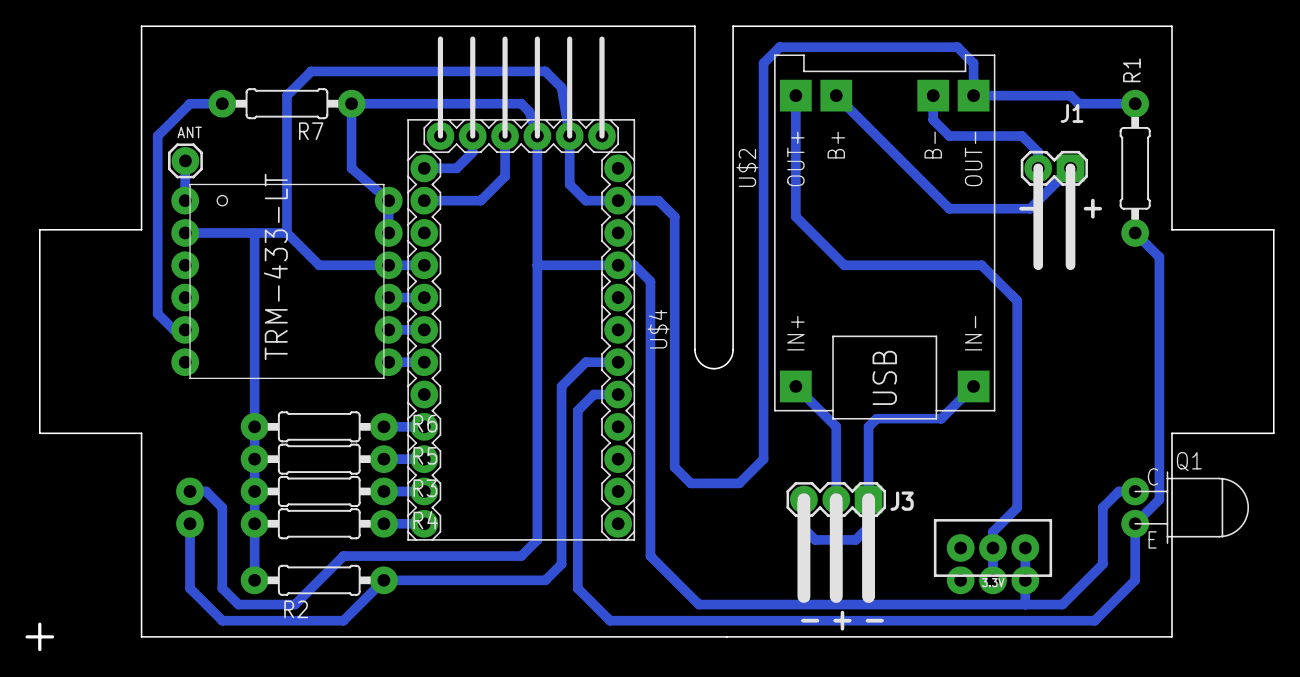
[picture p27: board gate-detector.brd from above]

Board: 2 copper layers, 98.0 x 49.0 mm, 16 parts (1 on the bottom side), 20 nets.

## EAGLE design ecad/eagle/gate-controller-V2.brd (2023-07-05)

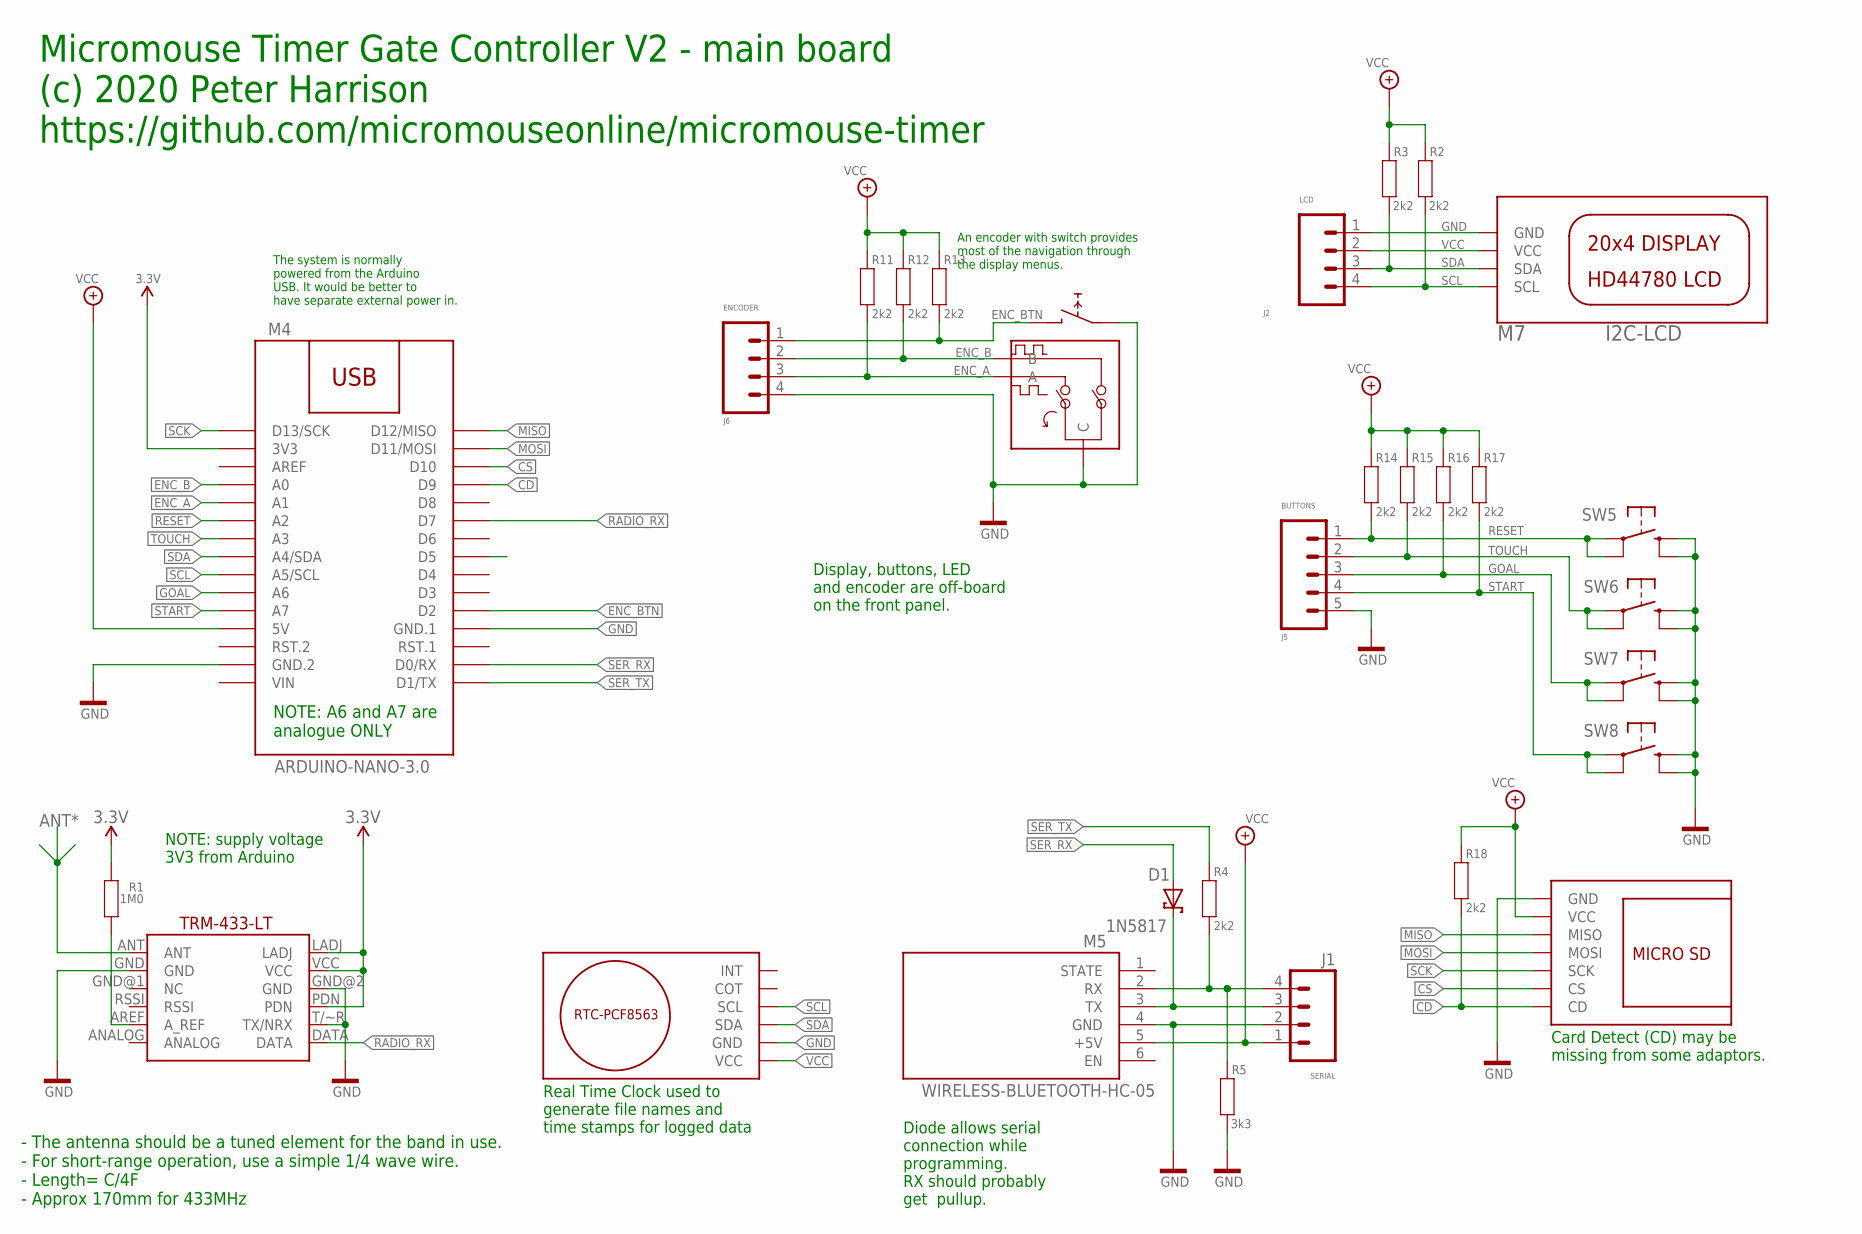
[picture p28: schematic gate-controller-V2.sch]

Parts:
D1: 1N5817; DO35-7
J1: SERIAL; 1X04
J2: LCD; 1X04
J5: BUTTONS; 1X05
J6: ENCODER; 1X04
M2: RTC-PCF8563
M3: TRM-433-LT; LINX-TRM-433-LT
M4: ARDUINO-NANO-3.0
M5: WIRELESS-BLUETOOTH-HC-05
M6: MICRO-SD-ADAPTOR
R1: 1M0; AXIAL-0207_0.4
R2, R3, R4, R11, R12, R13, R14, R15, R16, R17, R18: 2k2; AXIAL-0207_0.4
R5: 3k3; AXIAL-0207_0.4

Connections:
3V3: M3.LADJ, M3.PDN, M3.VCC, M4.3V3, R1.2
ANT*: M3.ANT
CD: M4.D9, M6.CD, R18.1
CS: M4.D10, M6.CS
D5: M4.D5
ENC_A: J6.3, M4.A1, R11.1
ENC_B: J6.2, M4.A0, R12.1
ENC_BTN: J6.1, M4.D2, R13.1
GND: J1.2, J2.1, J5.5, J6.4, M2.GND, M3.GND, M3.GND@2 (GND), M3.T/~R (TX/NRX), M4.GND@1 (GND.2), M4.GND@2 (GND.1), M5.4 (GND), M6.GND, R5.1
GOAL: J5.3, M4.A6, R16.1
MISO: M4.D12 (D12/MISO), M6.MISO
MOSI: M4.D11 (D11/MOSI), M6.MOSI
unnamed: M3.AREF (A_REF), R1.1
unnamed: J1.4, M5.2 (RX), R4.1, R5.2
unnamed: D1.C, J1.3, M5.3 (TX)
RADIO_RX: M3.DATA, M4.D7
RESET: J5.1, M4.A2, R14.1
SCK: M4.D13 (D13/SCK), M6.SCK
SCL: J2.4, M2.SCL, M4.A5 (A5/SCL), R2.1
SDA: J2.3, M2.SDA, M4.A4 (A4/SDA), R3.1
SER_RX: D1.A, M4.RX0 (D0/RX)
SER_TX: M4.TX1 (D1/TX), R4.2
START: J5.4, M4.A7, R17.1
TOUCH: J5.2, M4.A3, R15.1
VCC: J1.1, J2.2, M2.VCC, M4.5V, M5.5 (+5V), M6.VCC, R2.2, R3.2, R11.2, R12.2, R13.2, R14.2, R15.2, R16.2, R17.2, R18.2
VIN: M4.VIN

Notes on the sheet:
- The antenna should be a tuned element for the band in use. - For short-range operation, use a simple 1/4 wave wire. - Length= C/4F - Approx 170mm for 433MHz
Micromouse Timer Gate Controller V2 - main board (c) 2020 Peter Harrison https://github.com/micromouseonline/micromouse-timer
Card Detect (CD) may be missing from some adaptors.
Diode allows serial connection while programming. RX should probably get pullup.
An encoder with switch provides most of the navigation through the display menus.
NOTE: supply voltage 3V3 from Arduino
Real Time Clock used to generate file names and time stamps for logged data
Display, buttons, LED and encoder are off-board on the front panel.
NOTE: A6 and A7 are analogue ONLY
The system is normally powered from the Arduino USB. It would be better to have separate external power in.

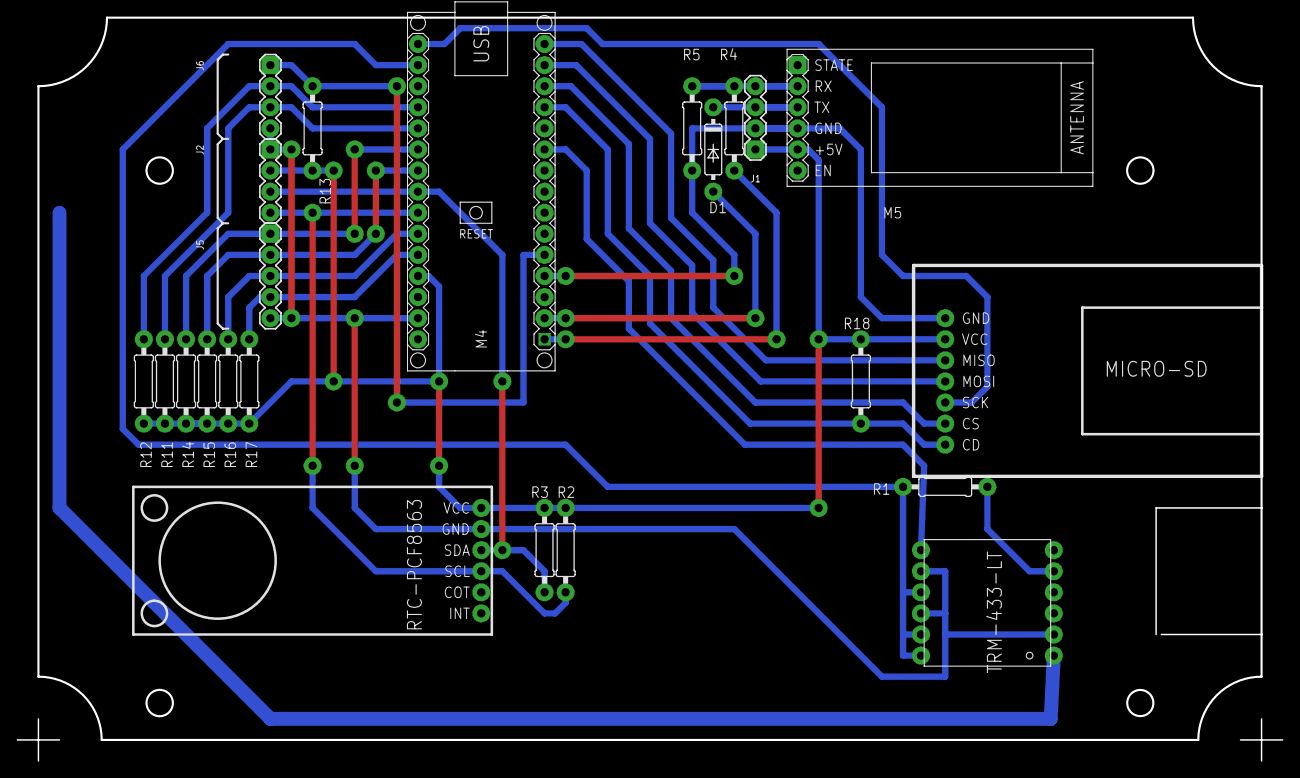
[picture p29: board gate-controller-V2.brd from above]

Board: 2 copper layers, 152.4 x 89.5 mm, 24 parts (0 on the bottom side), 23 nets.

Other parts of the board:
U$1: HAMMOND-1595-C-BOARD

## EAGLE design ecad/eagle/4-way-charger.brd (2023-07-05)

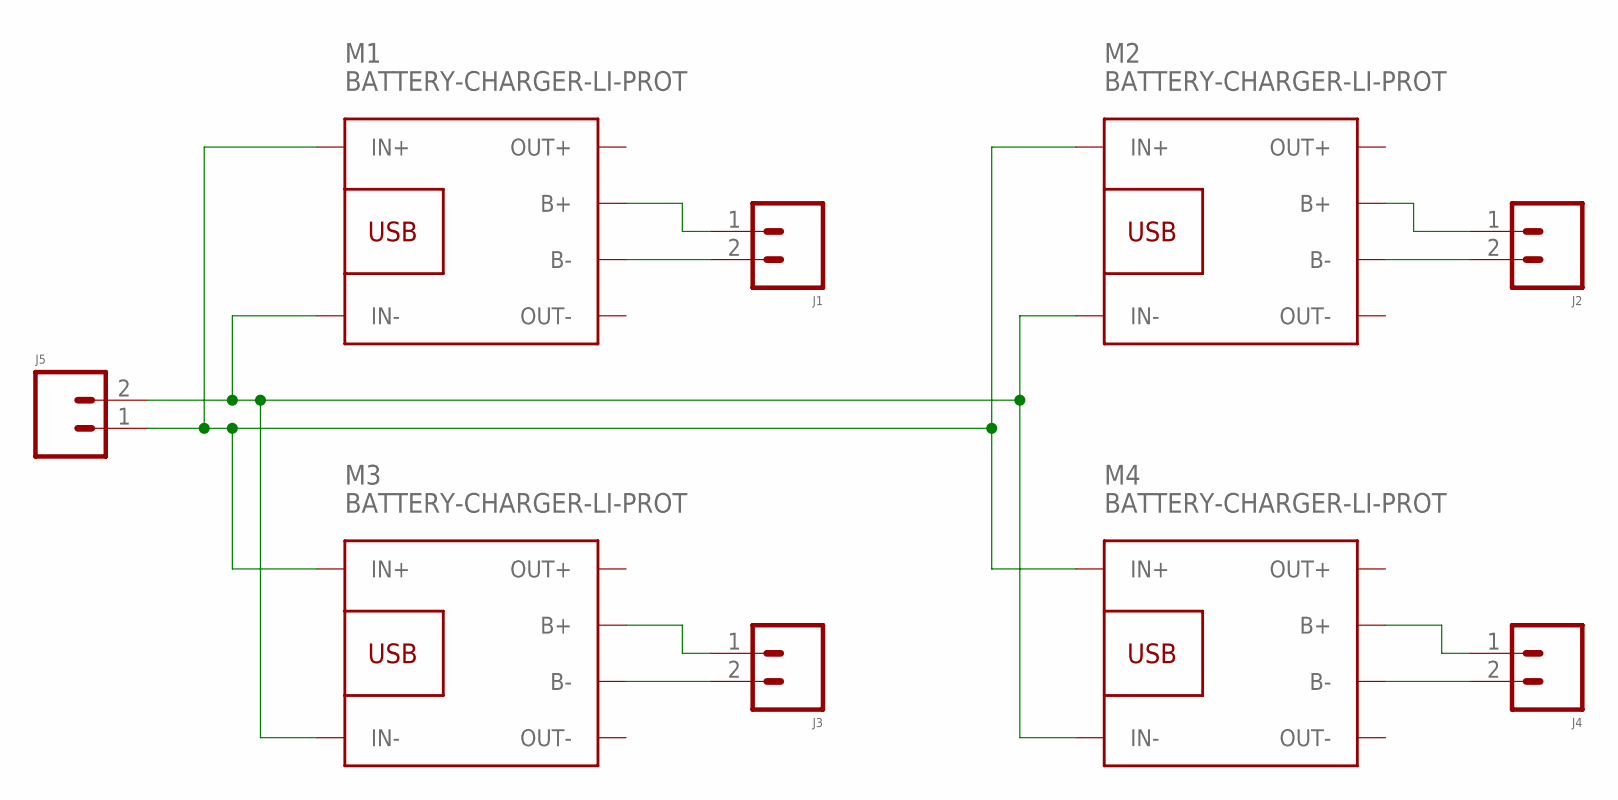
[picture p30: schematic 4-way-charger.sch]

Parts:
J1, J2, J3, J4, J5: M02RA_MALE_MILL; 1X02_RA_PTH_MALE_MILL
M1, M2, M3, M4: BATTERY-CHARGER-LI-PROT

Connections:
unnamed: J3.2, M3.B-
unnamed: J3.1, M3.B+
unnamed: J1.2, M1.B-
unnamed: J1.1, M1.B+
unnamed: J2.2, M2.B-
unnamed: J2.1, M2.B+
unnamed: J4.2, M4.B-
unnamed: J4.1, M4.B+
unnamed: J5.2, M1.IN-, M2.IN-, M3.IN-, M4.IN-
unnamed: J5.1, M1.IN+, M2.IN+, M3.IN+, M4.IN+

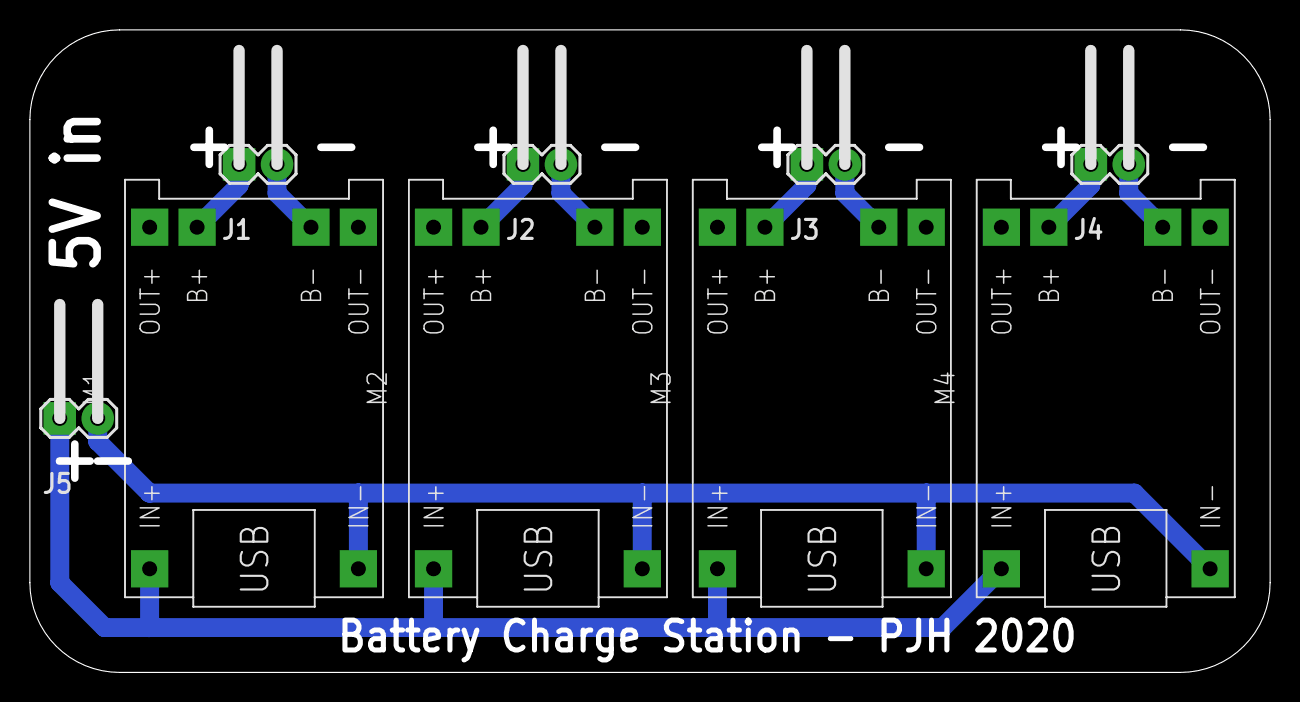
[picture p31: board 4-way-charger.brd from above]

Board: 2 copper layers, 83.0 x 43.0 mm, 9 parts (0 on the bottom side), 10 nets.

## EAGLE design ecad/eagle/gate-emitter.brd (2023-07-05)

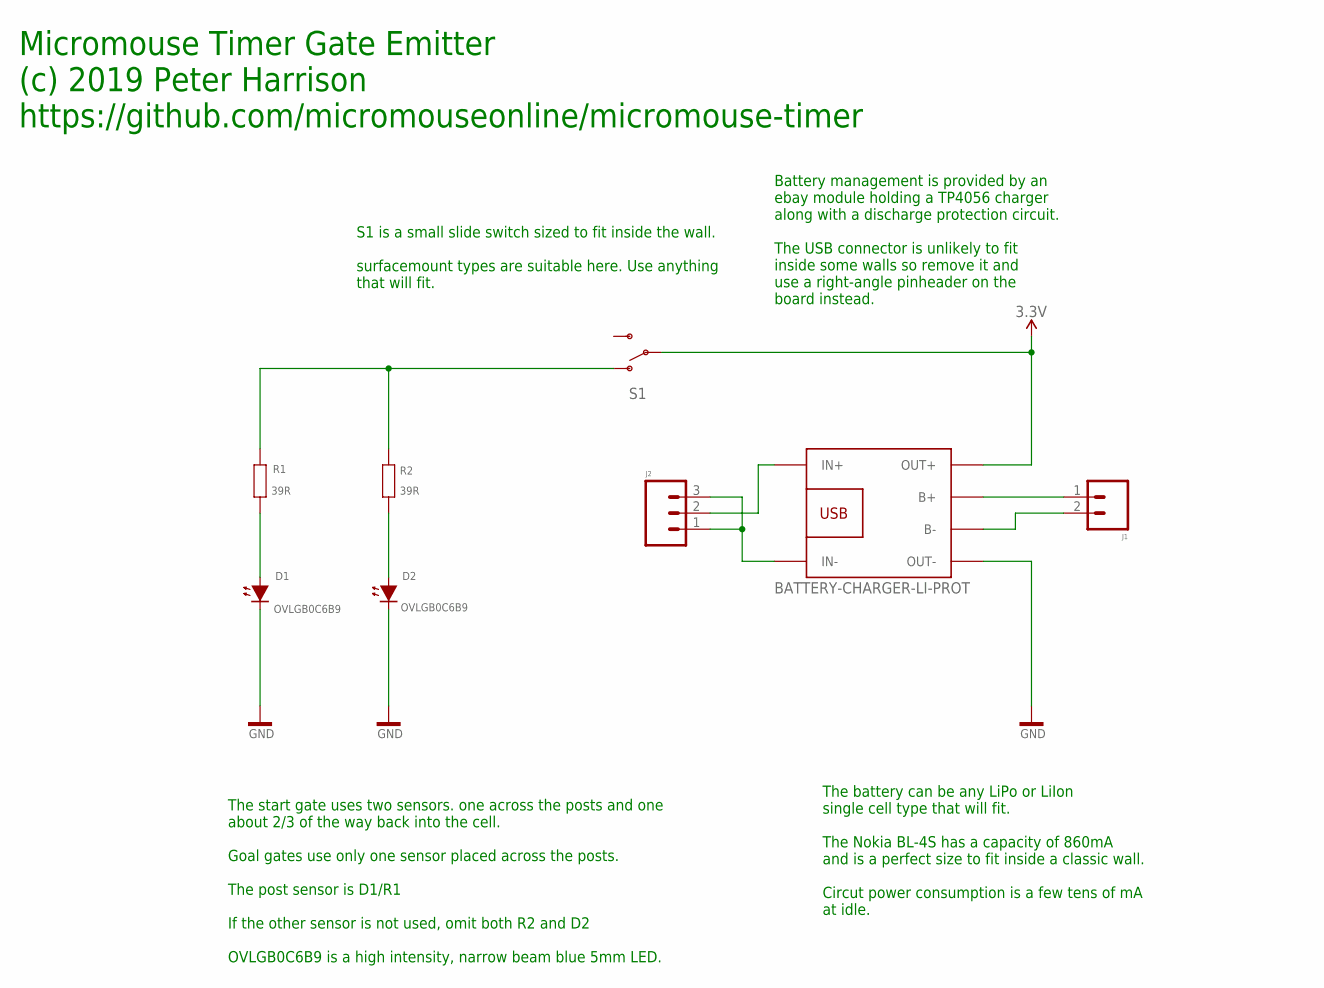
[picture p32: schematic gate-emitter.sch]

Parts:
D1, D2: OVLGB0C6B9; LED5MM-H
J1: M02RA_MALE_MILL; 1X02_RA_PTH_MALE_MILL
J2: M03RA_MALE; 1X03_RA_PTH_MILL
R1, R2: 39R; AXIAL-0207_0.4
S1: SWITCH-SPDT-PTH-11.6X4.0MM; SWITCH_SPDT_PTH_11.6X4.0MM
U$2: BATTERY-CHARGER-LI-PROT

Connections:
3.3V: S1.2, U$2.OUT+
GND: D1.C, D2.C, U$2.OUT-
unnamed: R1.2, R2.2, S1.1 (O)
unnamed: J1.1, U$2.B+
unnamed: D1.A, R1.1
unnamed: D2.A, R2.1
unnamed: J2.2, U$2.IN+
unnamed: J2.1, J2.3, U$2.IN-
unnamed: J1.2, U$2.B-

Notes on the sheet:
The start gate uses two sensors. one across the posts and one about 2/3 of the way back into the cell. Goal gates use only one sensor placed across the posts. The post sensor is D1/R1 If the other sensor is not used, omit both R2 and D2 OVLGB0C6B9 is a high intensity, narrow beam blue 5mm LED.
The battery can be any LiPo or LiIon single cell type that will fit. The Nokia BL-4S has a capacity of 860mA and is a perfect size to fit inside a classic wall. Circut power consumption is a few tens of mA at idle.
Battery management is provided by an ebay module holding a TP4056 charger along with a discharge protection circuit. The USB connector is unlikely to fit inside some walls so remove it and use a right-angle pinheader on the board instead.
Micromouse Timer Gate Emitter (c) 2019 Peter Harrison https://github.com/micromouseonline/micromouse-timer
S1 is a small slide switch sized to fit inside the wall. surfacemount types are suitable here. Use anything that will fit.

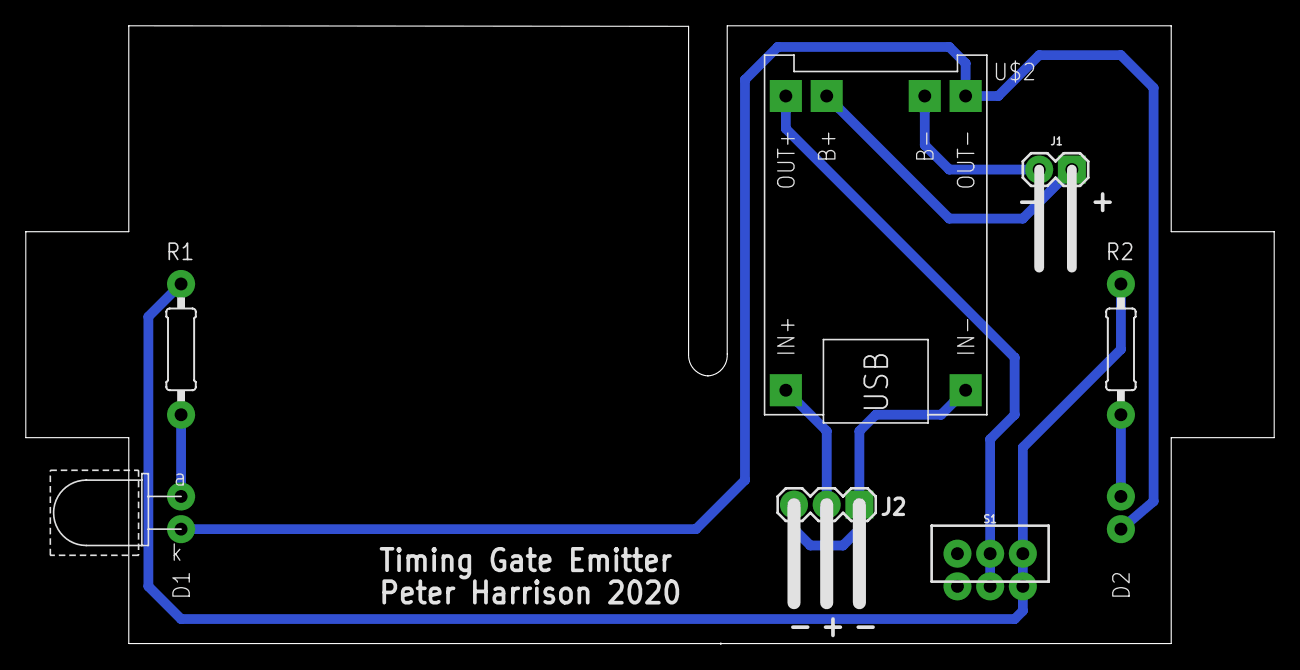
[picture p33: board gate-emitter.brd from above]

Board: 2 copper layers, 97.0 x 48.0 mm, 8 parts (1 on the bottom side), 9 nets.

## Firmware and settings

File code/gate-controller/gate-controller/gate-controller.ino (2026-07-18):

/***
 * Micromouse Timer
 * Gate Controller
 * (c) Peter Harrison 2020
 * Libraries:
 * https://bitbucket.org/fmalpartida/new-liquidcrystal/wiki/Home
 * https://platformio.org/lib/show/136/LiquidCrystal
 *
 * https://github.com/NeiroNx/RTCLib
 * https://platformio.org/lib/show/1197/RTCLib
 *
 *
 *
 */
#include <Arduino.h>
#include <LiquidCrystal_I2C.h>
#include <SoftwareSerial.h>
#include <Wire.h>
#include <avr/wdt.h>
#include <sdcard.h>
#include "RTClib.h"
#include "button.h"
#include "messages.h"
#include "pins.h"
#include "stopwatch.h"
#include "utils.h"

///////////////////////////////////////////////////////////////////
// click button on the encoder
BasicButton encoderButton(ENC_BTN, BasicButton::ACTIVE_LOW);
// Front panel buttons
BasicButton startButton(BUTTON_START, BasicButton::ACTIVE_LOW, BasicButton::ANALOG);
BasicButton goalButton(BUTTON_GOAL, BasicButton::ACTIVE_LOW, BasicButton::ANALOG);
BasicButton armButton(BUTTON_ARM, BasicButton::ACTIVE_LOW, BasicButton::ANALOG);
BasicButton resetButton(BUTTON_RESET, BasicButton::ACTIVE_LOW, BasicButton::ANALOG);

const uint8_t BTN_NONE = 0;
const uint8_t BTN_GREEN = 1;
const uint8_t BTN_YELLOW = 2;
const uint8_t BTN_RED = 4;
const uint8_t BTN_BLUE = 8;
const uint8_t BTN_ENCODER = 16;

volatile uint8_t button_state = BTN_NONE;

const uint32_t watchdog_interval = 1000;  // milliseconds
uint32_t g_watchdog_time;
uint16_t g_watchdog_id;
/***
 * Note that the adress of the I2C expander depends on the exact
 * chip version and the theree address links.
 * There are two common choices for the expander.
 *
 * The PCF8574T has a basic address of 0x27 with no links bridged
 * The PCF8574AT has a basic address of 0x3F with no links bridged
 *
 * The address bridges, A0..A2 clear the corresponding bits in the
 * address. Thus, bridging all the links would make the addresses
 * 0x20 and 0x38 respectively.
 *
 * Also note that the LiquidCrystal_I2C library, like many Arduino
 * sketches/libraries, uses a right-justified address.
 */
// I2C LCD pin numbers are on the extender chip - not the arduino
LiquidCrystal_I2C lcd(0x3f, 2, 1, 0, 4, 5, 6, 7, 3, POSITIVE);

/***
 * The PCF8563 library expects a left-justified address. Hence the
 * multiplication by two in the constructor
 */
PCF8563 rtc(0x51 * 2);

/***
 * The radio is used only in receive mode here but the SoftwareSerial requires
 * two pins for the configuration. TX is not used
 */
SoftwareSerial radio(RADIO_RX, RADIO_TX);  // RX, TX

Stopwatch mazeTimer;
Stopwatch runTimer;
uint32_t g_maze_time;
uint32_t g_run_time;
uint32_t g_run_start_time;
uint32_t g_maze_start_time;
uint32_t bestTime = UINT32_MAX;
int runCount = 0;

// Some used defined characters for the LCD display
const char c0[] PROGMEM = {0x4, 0x0, 0x0, 0x0, 0x0, 0x0, 0x4, 0x4};
const char c1[] PROGMEM = {0x4, 0x4, 0x4, 0x0, 0x0, 0x0, 0x0, 0x0};
const char c2[] PROGMEM = {0x0, 0x0, 0x4, 0x4, 0x4, 0x0, 0x0, 0x0};
const char c3[] PROGMEM = {0x0, 0x0, 0x0, 0x0, 0x4, 0x4, 0x4, 0x0};
const char c4[] PROGMEM = {0x0, 0x0, 0x0, 0x0, 0x0, 0x0, 0x4, 0x4};
const char c5[] PROGMEM = {0x0, 0x0, 0xa, 0x1f, 0x1f, 0xe, 0x4, 0x0};  // closed heart
const char c6[] PROGMEM = {0x0, 0x0, 0xa, 0x15, 0x11, 0xa, 0x4, 0x0};  // open heart
const char c7[] PROGMEM = {0x0, 0x1, 0x3, 0x16, 0x1c, 0x8, 0x0, 0x0};  // tick

/***
 * The display only needs to be updated about 10-15 times per second
 * The interval is chosen to avoid aliasing of the counts when they are
 * displayed. If it were exactly 100ms, one of the digits may appear to
 * count slowly. Choose a prime number for least liklihood of aliasing.
 * The update interval should not affect any of the timing resolution or
 * accuracy though it takes a bit of time for each update
 */
const uint32_t displayUpdateInterval = 23;  // milliseconds
uint32_t displayUpdateTime;

// divisors for unpacking millisecond timestamps
const uint32_t ONE_SECOND = 1000L;
const uint32_t ONE_MINUTE = 60 * ONE_SECOND;
const uint32_t ONE_HOUR = 60 * ONE_MINUTE;

const uint32_t TIME_TRIAL_LOCKOUT = 2000;
// Multi purpose states for the various contest state machines
const int ST_CALIBRATE = 0;  // calibrate gates,
const int ST_WAITING = 1;    // looking for mouse in start cell,
const int ST_ARMED = 2;      // Mouse seen in start cell,
const int ST_STARTING = 3;   // Run started (but not cleared start gate yet) ------ NEVER USED
const int ST_RUNNING = 4;    // Run in progress,
const int ST_GOAL = 5;       // Run to centre completed (finish gete triggered)
const int ST_NEW_MOUSE = 6;  // Set up for new mouse

int contestState = ST_WAITING;

enum { CT_NONE = 0, CT_MAZE, CT_TRIAL, CT_RADIO };
int contest_type = CT_MAZE;
enum { GATE_NONE, GATE_ARM, GATE_START, GATE_GOAL, GATE_RESET };

////////////////////////////////////////////////////////////////////////////
// This is only going to work with an ATMega328 processor - take care  ////
// The ATMega328P in ther arduino nano/un has a bootloader installed at the
// top of flash. The default fuse values set aside just 515 bytes (256 words)
// for the  bootloader so it must start at FLASH_END - 0x100 = 0x7E00
// the fuses are also programmed so that the external reset vector points to
// the bootloader rather than adress 0x0000.
// The bootloader code sets the watchdog timer value to oone second. This,
// if it receives no valid instructions in that time the processor is reset
// to address 0x000 with all the registers (except MCUSR and SP) set to
// their power on values. Note that some versions of the bootloader will
// clear the MCUSR so that it is not possible to reliably detect the
// cause of a reset.
// The result of all this is that the Arduino can be reliably reset by simply
// jumping to the bootloader. Assuming there is not a programmer trying to
// send it commands of course.
// This is also a good way to start a firmware update from the existing
// firmware.
////////////////////////////////////////////////////////////////////////////

void (*reset_function_zero)(void) = 0;                         // reset function at address 0
void (*reset_function_bootloader)(void) = (void (*)())0x7E00;  // bootloader entry point

void reset_processor() {
#if defined(__AVR_ATmega328P__) || defined(__AVR_ATmega328__)
  cli();
  reset_function_bootloader();  //
#endif
}

////////////////////////////////////////////////////////////////////////////

int8_t gEncoderValue = 0;
int8_t gEncoderClicks = 0;
const int ENC_COUNTS_PER_CLICK = 4;
const int8_t deltas[16] PROGMEM = {0, 1, -1, 0, -1, 0, 0, 1, 1, 0, 0, -1, 0, -1, 1, 0};

void encoderUpdate() {
  static uint8_t bits = 0;
  bits <<= 2;
  bits |= digitalRead(ENC_B) ? 2 : 0;
  bits |= digitalRead(ENC_A) ? 1 : 0;
  bits &= 0x0f;
  gEncoderValue += pgm_read_word(deltas + bits);
  gEncoderClicks = gEncoderValue / ENC_COUNTS_PER_CLICK;
}
/***************************************************   Encoder end */

/*********************************************** BUTTON ******************/
void buttonsUpdate() {
  startButton.update();
  goalButton.update();
  armButton.update();
  resetButton.update();
  encoderButton.update();
  button_state = BTN_NONE;
  if (armButton.isPressed()) {
    button_state |= BTN_GREEN;
  }
  if (startButton.isPressed()) {
    button_state |= BTN_YELLOW;
  }
  if (goalButton.isPressed()) {
    button_state |= BTN_RED;
  }
  if (resetButton.isPressed()) {
    button_state |= BTN_BLUE;
  }
}
/*********************************************** BUTTONS END ******************/

void show_trial_screen() {
  lcd.clear();
  lcd.setCursor(0, 0);
  lcd.print(F("TRIAL      Run:"));
  lcd.setCursor(0, 1);
  lcd.print(F("Trial Time"));
  lcd.setCursor(0, 2);
  lcd.print(F("  Run Time"));
  lcd.setCursor(0, 3);
  lcd.print(F(" Best Time"));
}

void showMazeScreen() {
  lcd.clear();
  lcd.setCursor(0, 0);
  lcd.print(F("MAZE       Run:"));
  lcd.setCursor(0, 1);
  lcd.print(F("Maze Time"));
  lcd.setCursor(0, 2);
  lcd.print(F(" Run Time"));
  lcd.setCursor(0, 3);
  lcd.print(F("Best Time"));
}

/*********************************************** systick ******************/
/***
 * Systick runs every 2ms. It is used to sample the encoder so it must run
 * frequently enough to catch all the encoder states even if the user
 * spins the knob quickly.
 */
void setupSystick() {
  // set the mode for timer 2 as regulr interrupts
  bitClear(TCCR2A, WGM20);
  bitSet(TCCR2A, WGM21);
  bitClear(TCCR2B, WGM22);
  // set divisor to  => timer clock, Fclk = 125kHz
  bitSet(TCCR2B, CS22);
  bitClear(TCCR2B, CS21);
  bitSet(TCCR2B, CS20);
  // timer interval is (n+1)/Fclk seconds
  OCR2A = 249;             // 0.002 * 125000 - 1 = 249
  bitSet(TIMSK2, OCIE2A);  // enable the timer interrupt
}

inline void systick() {
  encoderUpdate();
  buttonsUpdate();
}

// the systick event is an ISR attached to Timer 2
ISR(TIMER2_COMPA_vect) {
  systick();
}
/*********************************************** systick  end******************/

void set_state(int new_state) {
  contestState = new_state;
  const __FlashStringHelper *comment = F("");
  switch (contestState) {
    case ST_CALIBRATE:
      comment = F(" CALIBRATE");
      break;
    case ST_NEW_MOUSE:
      comment = F(" INIT     ");
      break;
    case ST_WAITING:
      comment = F(" WAITING  ");
      break;
    case ST_ARMED:
      comment = F(" ARMED    ");
      break;
    case ST_STARTING:
      comment = F(" STARTING ");
      break;
    case ST_RUNNING:
      comment = F(" RUNNING  ");
      break;
    case ST_GOAL:
      comment = F(" GOAL");
      break;
    default:
      comment = F(" ????");
      break;
  }
  send_message(MSG_CURRENT_STATE, contestState, comment);  // log current state to PC
  showState();                                             // update the LCD
}

/*********************************************** process radio data ***/

// also used for gate ID
enum ReaderState { RD_NONE, RD_WAIT, RD_CONFIRM, RD_HOME, RD_START, RD_GOAL, RD_TERM, RD_TRIGGERED, RD_ERROR };

volatile ReaderState reader_state = RD_WAIT;
uint32_t gate_message_time;
int retry_count;
int gate_id = 0;
char last_char = '*';

void gate_reader(char c) {
  if (not isprint(c)) {
    return;
  }
  uint32_t time = millis();
  switch (reader_state) {
    case RD_WAIT:
      retry_count = 0;
      if (c >= '0' and c < '0' + 10) {
        last_char = c;
        gate_id = RD_GOAL;
        reader_state = RD_CONFIRM;
      } else if (c >= 'a' and c < 'a' + 10) {
        last_char = c;
        gate_id = RD_START;
        reader_state = RD_CONFIRM;

      } else if (c >= 'A' and c < 'A' + 10) {
        last_char = c;
        gate_id = RD_HOME;
        reader_state = RD_CONFIRM;
      }
      break;
    case RD_CONFIRM:

      if (c >= last_char && c < last_char + 6) {
        if (gate_id == RD_GOAL) {
          gate_message_time = time - 2 * (c - '0');
        } else if (gate_id == RD_START) {
          gate_message_time = time - 2 * (c - 'a');
        } else if (gate_id == RD_HOME) {
          gate_message_time = time - 2 * (c - 'A');
        } else {
          gate_message_time = time;  // this is an error
        }
        reader_state = RD_TERM;
      } else {
        if (++retry_count > 6) {
          gate_id = RD_NONE;
          reader_state = RD_WAIT;
        }
      }
    case RD_TERM:
      // if (c == '#') {
      if (gate_id == RD_HOME) {
        reader_state = RD_HOME;
      } else if (gate_id == RD_START) {
        reader_state = RD_START;
      } else if (gate_id == RD_GOAL) {
        reader_state = RD_GOAL;
      } else {
        reader_state = RD_WAIT;
      }
      break;
      // }
    case RD_HOME:
    case RD_START:
    case RD_GOAL:
      // stay in this state until acknowledged by the timer state machine
      break;
    default:
      reader_state = RD_ERROR;
      gate_id = RD_NONE;
      break;
  }
}

/*********************************************** time display functions ***/

/***
 * display timestamp as minutes, seconds and milliseconds - MM:SS.SSS
 * input time is in milliseconds
 * no validity checks are made
 */
void showTime(int column, int line, uint32_t time) {
  uint32_t ms = (time % 1000);
  uint32_t seconds = (time / ONE_SECOND) % 60;
  uint32_t minutes = (time / ONE_MINUTE) % 60;
  char lineBuffer[10] = {0};
  char *p = lineBuffer;
  *p++ = '0' + minutes / 10;
  *p++ = '0' + minutes % 10;
  *p++ = ':';
  *p++ = '0' + seconds / 10;
  *p++ = '0' + seconds % 10;
  *p++ = '.';
  *p++ = '0' + (ms / 100) % 10;
  *p++ = '0' + (ms / 10) % 10;
  *p++ = '0' + (ms / 1) % 10;
  lcd.setCursor(column, line);
  lcd.print(lineBuffer);
}

void showSystemTime(int column, int line) {
  DateTime now = rtc.now();
  char lineBuffer[24];
  strncpy(lineBuffer, "DD.MM.YYYY  hh:mm:ss\0", sizeof(lineBuffer));
  lcd.setCursor(column, line);
  lcd.print(now.format(lineBuffer));
}

/*********************************************** maze state machine *********/
void showState() {
  lcd.setCursor(0, 0);
  switch (contestState) {
    case ST_CALIBRATE:
      lcd.print(F("CALIBRATE"));
      break;
    case ST_NEW_MOUSE:
      lcd.print(F("INIT     "));
      break;
    case ST_WAITING:
      lcd.print(F("WAITING  "));
      break;
    case ST_ARMED:
      lcd.print(F("ARMED    "));
      break;
    case ST_STARTING:
      lcd.print(F("STARTING "));
      break;
    case ST_RUNNING:
      lcd.print(F("RUNNING  "));
      break;
    case ST_GOAL:
      lcd.print(F("GOAL     "));
      break;
    default:
      lcd.print(F("---------"));
      break;
  }
}

void displayInit() {
  lcd.setCursor(11, 3);
  lcd.print(F("--:--.---"));
  lcd.setCursor(17, 0);
  lcd.print(F("  "));
}

///////////////////////////////////////////////////////////////////

int old_state = 0;
void trial_machine() {
  if (resetButton.isPressed()) {
    set_state(ST_NEW_MOUSE);
    send_message(MSG_NewMouse, 0, F(" NEW MOUSE"));
    send_message(MSG_CourseTimeMs, 0, F(" RESET MAZE TIME"));
  }

  int gate = RD_NONE;
  if (reader_state == RD_HOME) {
    gate = RD_HOME;
    reader_state = RD_WAIT;
  }

  if (reader_state == RD_START) {
    gate = RD_START;
    reader_state = RD_WAIT;
  }
  if (reader_state == RD_GOAL) {
    gate = RD_GOAL;
    reader_state = RD_WAIT;
  }

  switch (contestState) {
    case ST_NEW_MOUSE:
      mazeTimer.reset();
      runTimer.reset();
      runCount = 0;
      bestTime = UINT32_MAX;
      displayInit();
      set_state(ST_ARMED);
      break;

    case ST_ARMED:  // robot in start cell, ready to run
      if (startButton.isPressed() || gate == RD_START) {
        bestTime = UINT32_MAX;
        if (runCount == 0) {
          send_message(MSG_CourseTimeMs, 0, F(" RESET MAZE TIME"));
          mazeTimer.restart();
          g_maze_start_time = millis();
        }
        send_message(MSG_C1SplitTime, 0, F(" RESET RUN TIME"));
        runTimer.restart();
        runCount++;
        set_state(ST_RUNNING);
      }
      break;
    case ST_RUNNING:  // robot on its way to the goal
      if (runTimer.time() < TIME_TRIAL_LOCKOUT) {
        break;
      }
      if (startButton.isPressed() || gate == RD_START) {
        runTimer.stop();
        g_run_time = runTimer.time();
        if (g_run_time < bestTime) {
          bestTime = g_run_time;
        }
        runCount++;
        runTimer.restart();

        send_message(MSG_C1RunTime, g_run_time, F(" RUN TIME"));
        delay(20);
        send_message(MSG_C1RunTime, g_run_time, F(" RUN TIME"));
        send_message(MSG_C1SplitTime, 0, F(" RESET RUN TIME"));
        set_state(ST_GOAL);
      }
      if (armButton.isPressed()) {
        runTimer.restart();
        set_state(ST_ARMED);
      }
      break;
    case ST_GOAL:  // transient state to record run time
      // manual timing may see the button held down for a while
      if (not startButton.isPressed()) {
        // runTimer.restart();
        // g_run_start_time = millis();
        // send_split_time(0);
        set_state(ST_RUNNING);
      }
    default:
      break;
  }
};

///////////////////////////////////////////////////////////////////

void mazeMachine() {
  if (resetButton.isPressed()) {
    set_state(ST_NEW_MOUSE);
    send_message(MSG_NewMouse, 0, F(" NEW MOUSE"));
    send_message(MSG_CourseTimeMs, 0, F(" RESET MAZE TIME"));
    while (resetButton.isPressed()) {
      delay(10);
    }
  }
  int gate = GATE_NONE;
  if (reader_state == RD_HOME) {
    gate = GATE_ARM;
    reader_state = RD_WAIT;
  }

  if (reader_state == RD_START) {
    gate = GATE_START;
    reader_state = RD_WAIT;
  }
  if (reader_state == RD_GOAL) {
    gate = GATE_GOAL;
    reader_state = RD_WAIT;
  }

  switch (contestState) {
    case ST_NEW_MOUSE:
      mazeTimer.reset();
      runTimer.reset();
      runCount = 0;
      bestTime = UINT32_MAX;
      displayInit();
      set_state(ST_WAITING);
      reader_state = RD_WAIT;
      gate_id = RD_NONE;
      break;
    case ST_WAITING:
      // if (armButton.isPressed() || (reader_state == RD_HOME)) {
      if (armButton.isPressed() || gate == GATE_ARM) {
        set_state(ST_ARMED);
        if (runCount == 0) {
          send_message(MSG_CourseTimeMs, 0, F(" RESET MAZE TIME"));
          mazeTimer.restart();
        }
        reader_state = RD_WAIT;
        while (armButton.isPressed()) {
          // delay(2);
        }
      }
      break;
    case ST_ARMED:  // robot in start cell, ready to run
      // if (startButton.isPressed() || reader_state != RD_NONE) {
      if (startButton.isPressed() || gate == GATE_START) {
        set_state(ST_RUNNING);
        send_message(MSG_C1SplitTime, 0, F(" RESET RUN TIME"));
        runTimer.restart();
        runCount++;
        reader_state = RD_WAIT;
        while (startButton.isPressed()) {
          delay(2);
        }
      }
      break;
    case ST_RUNNING:  // robot on its way to the goal
      if (goalButton.isPressed() || gate == GATE_GOAL) {
        // robot arrives at goal
        if (runTimer.time() < 500) {
          break;  /////////////////////////////////////// NASTY HACK
        }
        runTimer.stop();
        uint32_t time = runTimer.time();
        set_state(ST_GOAL);
        send_message(MSG_C1RunTime, time, F(" RUN TIME"));
        delay(20);
        send_message(MSG_C1RunTime, time, F(" RUN TIME"));
        if (time < bestTime) {
          bestTime = time;
          showTime(11, 3, bestTime);
        }
        // send_message(MSG_Watchdog, millis(), F(" timecheck"));
        reader_state = RD_WAIT;
        // break;
      }
      if (armButton.isPressed() || gate == GATE_ARM) {
        // robot is back in start cell or run is aborted
        runTimer.stop();
        runTimer.reset();
        set_state(ST_ARMED);
        reader_state = RD_WAIT;
        while (armButton.isPressed()) {
          delay(2);
        }
      }
      break;
    case ST_GOAL:
      if (armButton.isPressed() || gate == GATE_ARM) {
        // robot is back in start cell or run is aborted
        set_state(ST_ARMED);
        // send_message(MSG_Watchdog, millis(), F(" timecheck"));
        reader_state = RD_WAIT;
        while (armButton.isPressed()) {
          delay(2);
        }
      }
      break;
    default:
      break;
  }
}

void radio_test(char c) {
  switch (reader_state) {
    case RD_HOME:
      Serial.println(F("HOME    "));
      lcd.setCursor(0, 1);
      lcd.print(F("HOME    "));
      reader_state = RD_WAIT;
      break;

    case RD_START:
      Serial.println(F("START    "));
      lcd.setCursor(0, 1);
      lcd.print(F("START    "));
      reader_state = RD_WAIT;
      break;
    case RD_GOAL:
      Serial.println(F("GOAL    "));
      lcd.setCursor(0, 1);
      lcd.print(F("GOAL    "));
      reader_state = RD_WAIT;
      break;
    default:
      // Serial.println("----");
      // reader_state = RD_WAIT;
      break;
  }
}

int select_contest_type() {
  lcd.clear();
  lcd.setCursor(0, 0);
  lcd.print(F(" CONTEST TIMER V0.2 "));
  lcd.setCursor(0, 1);
  lcd.print(F(" GREEN: MAZE EVENT  "));
  lcd.setCursor(0, 2);
  lcd.print(F("YELLOW: TIME TRIAL  "));
  lcd.setCursor(0, 3);
  lcd.print(F("   RED: RADIO TEST  "));
  while (button_state != BTN_NONE) {
    delay(50);
  }
  delay(250);
  while (button_state == BTN_NONE) {
    delay(50);
  }
  int type = CT_MAZE;  // default
  if (button_state == BTN_GREEN) {
    type = CT_MAZE;
  } else if (button_state == BTN_YELLOW) {
    type = CT_TRIAL;
  } else if (button_state == BTN_RED) {
    type = CT_RADIO;
  }
  lcd.clear();
  while (button_state != BTN_NONE) {
    delay(100);
  }
  // delay(500);
  return type;
}
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
void loop() {
  char c;
  if (radio.available()) {
    c = radio.read();
    gate_reader(c);
  }

  if (Serial.available()) {
    char c = Serial.read();
    if (c == '>') {
      set_state(ST_NEW_MOUSE);
    }
  }
  if (button_state == (BTN_BLUE + BTN_GREEN)) {
    while (button_state != BTN_NONE) {
      // delay(10);
    }
    lcd.clear();
    reset_processor();
  }
  if (contest_type == CT_MAZE) {
    mazeMachine();
  } else if (contest_type == CT_TRIAL) {
    trial_machine();
  } else if (contest_type == CT_RADIO) {
    radio_test(c);
  } else {
    // do nothing
  }
  if (contest_type != CT_NONE && millis() > displayUpdateTime) {
    displayUpdateTime += displayUpdateInterval;
    switch (display_phase++) {
      case 0:
        lcd.setCursor(17, 0);
        lcd.print(runCount);
        break;
      case 1:
        showTime(11, 1, mazeTimer.time());
        break;
      case 2:
        showTime(11, 2, runTimer.time());
        break;
      case 3:
        if (bestTime < UINT32_MAX) {
          showTime(11, 3, bestTime);
        }
        break;
      default:
        display_phase = 0;
        break;
    }
  }
  // Finally, we check to see if it is time to sent a watchdog message
  if (millis() - g_watchdog_time > watchdog_interval) {
    g_watchdog_time = millis();
    // send_message(MSG_Watchdog, g_watchdog_id++, F(" WATCHDOG"));
  }
}

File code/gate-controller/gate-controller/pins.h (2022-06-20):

#ifndef PINS_H
#define PINS_H

#include <Arduino.h>

/// Pin Assignments
const int LED_2 = 3;
const int LED_3 = 4;
const int LED_4 = 5;
const int LED_5 = 6;

const int RADIO_RX = 7;
const int RADIO_TX = 8;
const int SD_DETECT = 9;
const int SD_SELECT = 10;
const int SD_MOSI = 11;
const int SD_MISO = 12;
const int SD_SCK = 13;

const int ENC_BTN = 2;
const int ENC_A = A0;
const int ENC_B = A1;

const int BUTTON_ARM = A7;
const int BUTTON_START = A6;  // analogue only
const int BUTTON_GOAL = A3;   // analogue only
const int BUTTON_RESET = A2;

const int I2C_SDA = A4;
const int I2C_SCL = A5;


#endif

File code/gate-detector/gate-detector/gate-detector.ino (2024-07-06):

#include "SoftwareSerial.h"
#include "digitalWriteFast.h"
#include <Arduino.h>

#define DEBUG 0
const int sideSensorPin = A0;
const int endSensorPin = A1;
const int SIDE_GATE = 0;
const int END_GATE = 1;

const int RADIO_DATA = 4;
const int RADIO_NC = 5;
const int RADIO_PDN = 2;
const int RADIO_TX = 3;

#define GATE_ID_PIN0 9
#define GATE_ID_PIN1 8
#define GATE_ID_PIN2 7
#define GATE_ID_PIN3 6

int gateID = 0;

const int PACKET_REPEATS = 3;
const int PACKET_REPEAT_INTERVAL = 50;
////////////////////////////////////////////////////////////////////////

/***
 * The exponential moving average (EMS) filter is a simple and
 * comutationally inexpensive low pass filter.
 *
 * small values of alpha give low cut-off frequencies and long
 * time constants.
 *
 * For a signal sampled at a frequency F, and filtered with a
 * filter constant alpha, the time constant is
 *
 *  tau = 1/(F*alpha)
 *
 * In this example, the slow filter has
 *
 *     F = 1300
 * alpha = 0.001
 *   tau = 1/1.3 = 0.77 seconds.
 *
 * For a step change, the filter will take 3*tau seconds to get to
 * 95% of the new output value. Here that equates to the slow filter
 * being ready in about 2.5 seconds
 *
 *
 */
class ExpFilter {
public:
  ExpFilter(){};

  explicit ExpFilter(float alpha, float value = 0.0f) { begin(alpha, value); };

  void begin(float alpha, float value = 0) {
    mAlpha = alpha;
    mValue = value;
  }

  float update(float newValue) {
    mValue += mAlpha * (newValue - mValue);
    return mValue;
  };

  void set_alpha(float alpha) { mAlpha = alpha; }

  float value() { return mValue; }

  void set_value(float value) { mValue = value; }

  float operator()() { return mValue; }

private:
  volatile float mAlpha = 1.0f;
  volatile float mValue = 0;
};

////////////////////////////////////////////////////////////////////////
class GateSensor {
  const uint32_t LOCKOUT_PERIOD = 50;

public:
  explicit GateSensor(int pin) : mSensorPin(pin) {
    slow.begin(0.000769);                 // tau = 1.000 seconds
    fast.begin((1.0 / (1300.0 * 0.002))); // tau = 0.002 seconds
  }

  void update() {
    mInput = analogRead(mSensorPin);
    // if (not mInterrupted) {
    slow.update(mInput);
    // }
    fast.update(mInput);
    // When sensor is occluded, light the LED. It stays on until triggered
    if (slow.value() < 10) {
      digitalWriteFast(LED_BUILTIN, 1);
      return;
    }
    // fast recovery after lengthy occlusion
    slow.set_value(max(slow.value(), fast.value()));
    // mDiff just lets us know when the sensor is properly lit
    mDiff = fabs(fast.value() - slow.value());
    // now do the actual detection with plenty of hysteresis
    if (fast.value() < 0.25 * slow.value()) {
      mInterrupted = true;
    }
    if (fast.value() > 0.75 * slow.value()) {
      arm();
      mInterrupted = false;
      mMessageSent = false;
    }
  }

  void arm() { mArmed = true; }

  void disarm() { mArmed = false; }

  bool armed() { return mArmed; }

  int mSensorPin;
  volatile float mInput;
  volatile float mDiff;
  ExpFilter slow;
  ExpFilter fast;
  volatile bool mInterrupted = false;
  volatile bool mMessageSent = false;
  volatile bool mArmed = true;
};

////////////////////////////////////////////////////////////////////////

SoftwareSerial radio(RADIO_NC, RADIO_DATA); // RX, TX

const uint32_t LOCKOUT_TIME = 200;
const uint8_t HOME_BASE = 0x41;
const uint8_t START_BASE = 0x61;
const uint8_t GOAL_BASE = 0x30;
// assume this is the start gate detector
uint8_t side_sensor_base = HOME_BASE;
uint8_t end_sensor_base = START_BASE;

GateSensor endSensor(endSensorPin);
GateSensor sideSensor(sideSensorPin);

void analogueInit() {
  // increase speed of ADC conversions
  // by changing the clock prescaler from 128 to 32
  bitSet(ADCSRA, ADPS0);
  bitClear(ADCSRA, ADPS1);
  bitSet(ADCSRA, ADPS2);
}

// the systick event is an ISR attached to Timer 2
void systickInit() {
  // set the mode for timer 2
  bitClear(TCCR2A, WGM20);
  bitSet(TCCR2A, WGM21);
  bitClear(TCCR2B, WGM22);
  // set divisor to 128 => timer clock = 125kHz
  bitSet(TCCR2B, CS22);
  bitClear(TCCR2B, CS21);
  bitSet(TCCR2B, CS20);
  // set the timer frequency for 1300Hz
  OCR2A = (F_CPU / 128 / 1300) - 1; // 47
  bitSet(TIMSK2, OCIE2A);           // enable the timer interrupt
}

ISR(TIMER2_COMPA_vect) {
  endSensor.update();
  if (gateID == 0) {
    sideSensor.update();
  }
}

/***
 * In an attempt to get reliable timing from the software serial
 * strings are sent by calling directly the write method.
 *
 * At a baud rate of 5000 Baud, each character should take 2ms
 * to go out. Placing a 1ms delay between characters will let
 * the receiver calculate, from the character received, the time
 * that the first character was sent since they should be arriving
 * every 3ms.
 *
 * Software serial turns off interrupts while it is sending a byte
 * in order to get good timing.
 *
 * Here, interrupts are turned off for the duration of the entire
 * string to try and get good inter-character timing as well.
 *
 * Even so, there will be some jitter. Observations indicate that
 * this amounts to less than 250us variation between characters.
 *
 * Although a longer interval might make the system more resistant
 * to interference, it seems a good idea to get the entire packet
 * out in a short space of time. Packets contain 13 characters and
 * so should take up about 40ms transmission time.
 *
 * If messages are missed it might be a good idea to implement some
 * kind of repeat although that would considerably complicate the
 * implied timing scheme used here.
 *
 */
void sendString(char *s) {
  uint8_t oldSREG = SREG;
  cli();
  while (char c = *s++) {
    radio.write(c);
    delayMicroseconds(1000); // actual transmission is 11 bits?
  }
  SREG = oldSREG;
}

/***
 * The trigger message consists of a synchronising byte
 * followed by 6 data bytes and finished with a pair of
 * terminating bytes.
 *
 * The synchronising byte is used only to help the
 * receiver wake up. The receiver ignores that byte and
 * so it represents a fixed delay in the response.
 *
 */

uint32_t last_trigger_time = millis();
void send_trigger(uint8_t base) {
  digitalWriteFast(LED_BUILTIN, 1);
  digitalWrite(RADIO_DATA, 1);
  digitalWrite(RADIO_PDN, 1);
  digitalWrite(RADIO_TX, 1);
  // allow the transmitter to stabilise
  delayMicroseconds(500);
  switch (base) {
  case GOAL_BASE:
    sendString("U0123456789##");
    break;
  case HOME_BASE:
    sendString("UABCDEFGHIJ##");
    break;
  case START_BASE:
    sendString("Uabcdefghij##");
    break;
  }
  digitalWrite(RADIO_TX, 0);
  digitalWrite(RADIO_PDN, 0);
  digitalWriteFast(LED_BUILTIN, 0);
#if DEBUG == 0
  uint32_t now = millis();
  uint32_t elapsed = millis() - last_trigger_time;
  last_trigger_time = now;
  println(elapsed);
#endif
}

uint32_t next_update_time = millis();
uint32_t debug_update_interval = 50;
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

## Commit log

2019-12-28 add emitter schematic
2019-12-29 update detector schematic
2020-01-02 add gate controller schematic
2020-01-05 update gate controller schematics
2020-01-06 add LED display
2020-01-07 remove LED display
2020-01-07 add pullups and re-arrange buttons
2020-01-08 tidy the controller schematic a little
2020-01-13 images of the first prototype
2020-01-15 resize images of the first prototype
2020-01-17 tidy up code and reduce footprint
2022-06-11 track travis file
2022-06-20 track the combined state of the buttons
2022-06-20 add facility to reset controller from buttons
    [gate-controller.ino]
2022-06-20 don't track encoder button state
2022-06-20 simplify the button class
2022-06-20 and a little tidy of button.h
2022-07-13 tighten up the message timing
    [gate-detector.ino]
2023-07-05 add all project files to repository
    [4-way-charger-brd-nofill.dxf, 4-way-charger-fill.dxf, 4-way-charger-outline.dxf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]
2024-06-26 reset waits for button release
    [gate-controller.ino]
2024-07-06 reset defaults to maze timer reset with button down to change mode
    [gate-controller.ino]
2024-07-06 defines the reset vector more flexibly
    [gate-controller.ino]
2024-07-17 prevent multiple messages when pressing two buttons
    [gate-controller.ino]
2024-07-18 skip run times of less than 500ms
    [gate-controller.ino]
